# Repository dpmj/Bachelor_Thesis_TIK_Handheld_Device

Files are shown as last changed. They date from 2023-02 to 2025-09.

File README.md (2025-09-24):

# Tree Inspection Kit (TIK) hardware

This repository contains the hardware source from my bachelor's thesis in telecommunications engineering at the University of Granada, Spain, 2022. For the firmware, see this other repo: [Tree Inspection Kit (TIK) firmware](https://github.com/dpmj/bachelors-thesis-tree-inspection-kit-firmware).

This project marks the beginning of the development of a handheld device that can measure the modulus of elasticity of wood, a figure of great value for structural purposes, in a non-destructive way by analyzing acoustic signals. Developed with the help of the GranaSAT Electronics Aerospace Group and the IDIE-ADIME Institute, this project is part of the European LIFE Wood for Future initiative. The project encompasses every step in developing an electronic product, including conception, requirements specification, architecture and components selection, topology selection, circuit and PCB design, mechanical design, manufacturing, assembly, firmware, and prototype fabrication. 

Third-party desing elements included in this repository are subject to the copyright of their respective owners.

```bibtex
@phdthesis{dpmj-tfg-2022,
    title = {Development of an acoustic measurement system of the Modulus of Elasticity in trees, logs and boards},
    author = {{Del Pino Mena}, Juan},
    type = {Bachelor's thesis},
    school = {Universidad de Granada},
    year = {2022},
    month = {9},
    url = {https://hdl.handle.net/10481/80476},
    doi = {https://doi.org/10.5281/zenodo.13935041}
}
```

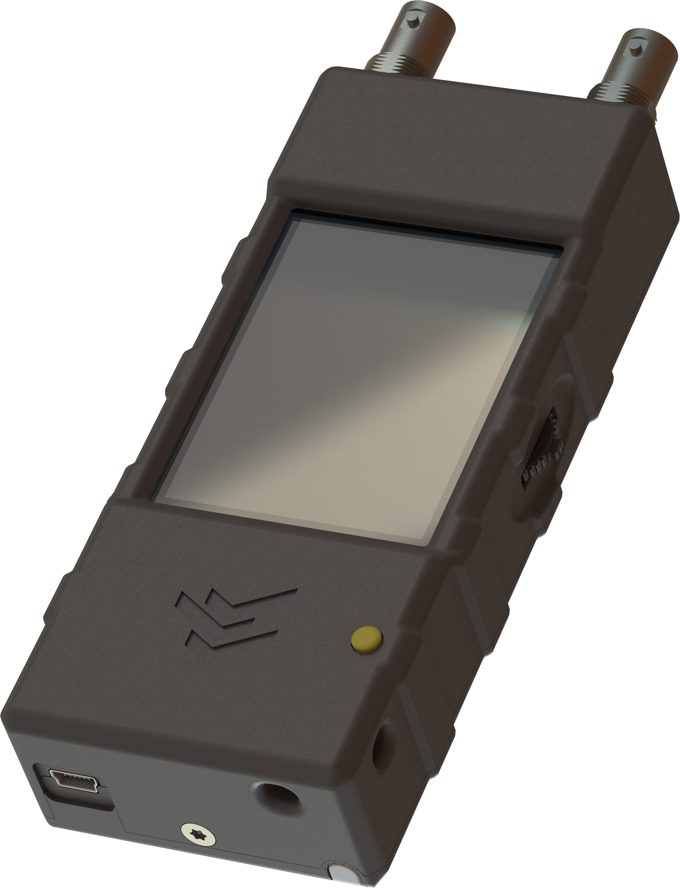
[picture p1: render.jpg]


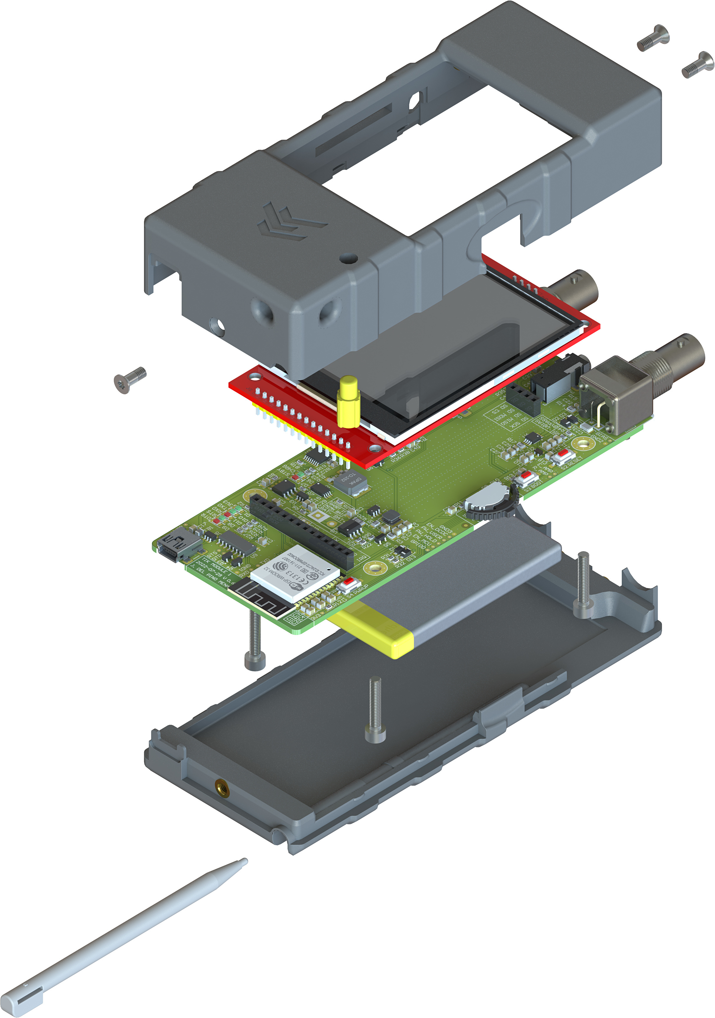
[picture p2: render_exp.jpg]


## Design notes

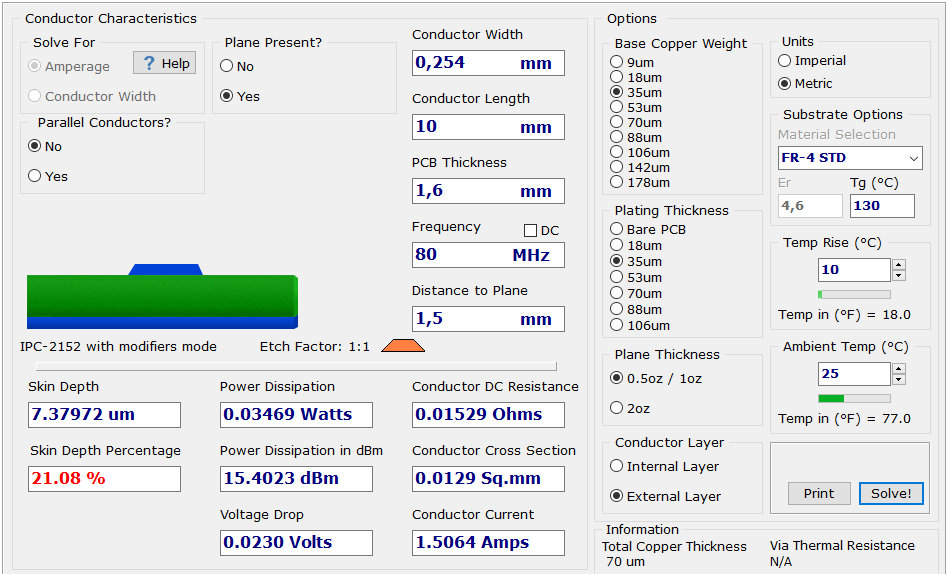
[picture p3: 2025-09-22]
ASSETS/IMAGES/SATURN PCB DESIGN/TRACE_0254mm_2.png

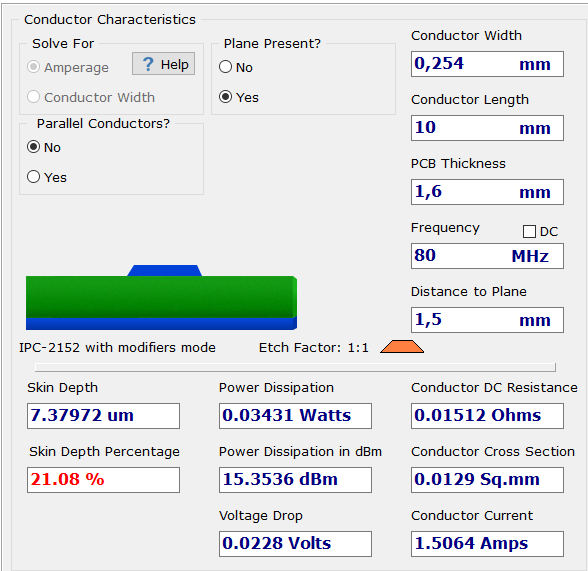
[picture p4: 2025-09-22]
ASSETS/IMAGES/SATURN PCB DESIGN/TRACE_0254mm.png

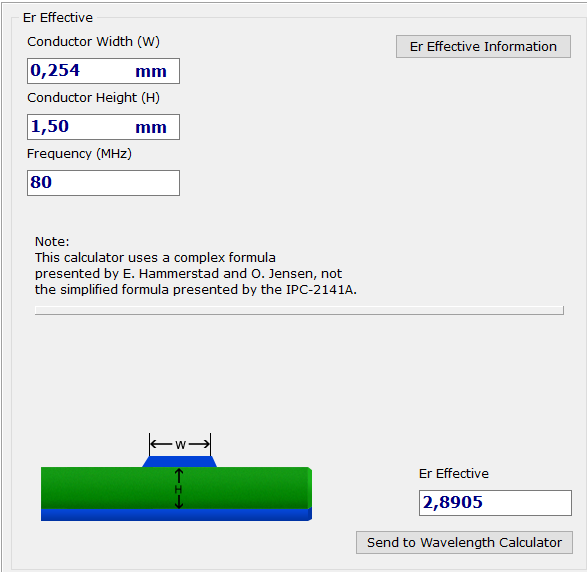
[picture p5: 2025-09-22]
ASSETS/IMAGES/SATURN PCB DESIGN/Er_Eff.png

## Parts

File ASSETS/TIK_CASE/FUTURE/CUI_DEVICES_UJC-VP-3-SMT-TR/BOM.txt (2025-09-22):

3DX_CUI_DEVICES_Supplier: CUI Devices
3DX_CUI_DEVICES_Description: Type C, 20 Vac, 3 A, Vertical, Surface Mount, Power-Only USB Receptacle
3DX_CUI_DEVICES_Model Number: UJC-VP-3-SMT-TR

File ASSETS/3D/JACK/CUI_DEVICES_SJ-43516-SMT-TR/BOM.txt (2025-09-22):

3DX_CUI_DEVICES_Supplier: CUI Devices
3DX_CUI_DEVICES_Description: 4 conductor 3.5 mm Surface Mount Audio Jack w/ Two Switch
3DX_CUI_DEVICES_Model Number: SJ-43516-SMT-TR

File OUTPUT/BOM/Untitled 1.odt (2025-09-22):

Designator | Value | Description | Quantity
C22 | 100pF | Ceramic cap size 0805 | 1
C23, C24 | 100nF | Ceramic cap size 1206 C1206C104K1RACTU | 2
C25 | 22pF | Ceramic cap size 0805 | 1
FB1, FB2 | 40mR, 3A 25% | 0805, 60O, 3A, 25% SMT | 2
J5 | | 3.5mm Jack 4-pole with normally closed switches | 1
J6 | | 3.5mm Jack 4-pole with normally closed switches | 1
L1 | 2.2uH | Shielded Power Inductor 2.2 uH 20% 2.2 A 50.4 mohms 3.11 A (sat) 60MHz 4018: 4x4x1.8mm | 1
Q1 | | Dual N-channel Enhancement mode power MOSFET | 1
Q2 | | MJD210 PNP BJT transistor DPAK (decawatt) 5A dc | 1
Q6 | | 65 V, 100 mA PNP general-purpose transistor | 1
R1 | 150K | Res size 0805 SMD mounting, low power Yageo-RC0805FR-07150KL | 1
R8 | 1.2K | Res size 0603 SMD mounting, low power | 1
R14, R17 | 1M | Res size 0805 SMD mounting, low power. Yageo-RC0805FR-071ML | 2
R23, R24 | 220 | Res size 0603 SMD mounting, low power | 2
R26, R27, R28, R29 | 150 | Res size 0603 SMD mounting, low power | 4
R36 | 22K | Res size 0603 SMD mounting, low power | 1
RT1 | 10K | NTC THERMISTOR 10K for solding a cable from the battery NTC | 1
U1 | | 1.0MHZ, 2A STEP-DOWN DC-DC BUCK CONVERTER, with latch-off protection | 1
U2 | LDO 1.8V, 80mA | Fixed output lowdropout linear regulator. 1.8 V 80 mA | 1
U6 | | LMV358IDGKR Dual OpAmp; low voltage rail to rail opamp; 2.7V to 5V Vss; ESD protection; MSOP-8 Package. | 1
U10 | | HX711 load cell amplifier | 1
U11 | | TPD3S014TDBVRQ1 ESD prot. & current limit | 1
C1, C14, C34 | 47pF | Ceramic cap size 0805 | 3
C2, C8, C13, C15, C17, C18, C20, C21, C27, C30, C31, C32, C33, C35, C37, C39, C40, C41, C42 | 100nF | Ceramic cap size 0805 | 19
C3, C16, C26, C29, C36, C38 | 10uF | Ceramic cap size 0805 | 6
C5 | 27pF | Ceramic cap size 0805 | 1
C4, C6, C7, C9, C12, C43 | 22uF | Ceramic cap size 0805 CC0805MKX5R6BB226 Yageo MLCC 22uF 10V 20% X5R | 6
C10, C11, C19 | 1uF | Ceramic cap size 0805 | 3
C28 | 470pF | Ceramic cap size 0805 | 1
D2, D3, D4, D5, D12, D13 | | SURFACE MOUNT FAST SWITCHING DIODE | 6
D1, D6, D8, D10 | | Low power LED color Green | 4
D7, D9, D11 | | Low power LED color Red | 3
J1 | | USB-MINI-B Female, Manufacturer PN/ID: 10033526-N3212LF | 1
J2, J3 | | BNC coaxial female connector | 2
J4 | | ILI9341 TFT LCD Jumper pin headers., plus SD card reader pins | 1
MCU1 | | - Transceiver; 802.11 b/g/n _Wi-Fi, WiFi, WLAN_, Bluetooth Smart Ready 4.x Dual Mode For Use With ESP-WROOM-32 | 1
Q3, Q4 | | | 2
Q5 | | PMOS BSS84AK | 1
R18, R21, R22 | 4.7K | Res size 0603 SMD mounting, low power | 3
R3 | 33K | Res size 0805 SMD mounting, low power | 1
R4, R5, R25 | 0R | Res size 0603 SMD mounting, zero-ohm 0R Yageo RC0603JR-070RL | 3
R9, R10, R11, R12, R13, R35, R37, R38, R39, R40 | 10K | Res size 0603 SMD mounting, low power | 10
R2, R6, R33, R34 | 100R | Res size 0603 SMD mounting, low power | 4
R7, R15, R16 | 1K | Res size 0603 SMD mounting, low power | 3
R19 | 1.5K | Res size 0603 SMD mounting, low power | 1
R20 | 0.2R | Res size 1206 SMD mounting, high power, shunt, current sense. | 1
R30, R31, R32 | 100K | Res size 0603 SMD mounting, low power | 3
S1 | | SWITCH Multidirection Slide Push Button SMD TS-003 | 1
S2, S3, S4 | | Generic 2 pin button | 3
U3 | | DW01A One cell Li-Po/Li-ion Battery protection IC | 1
U4 | | 1A Standalone Linear Li-lon Battery Charger with Thermal Regulation in SOP-8 | 1
U5 | | Very low capacitance ESD protection | 1
U7 | | LTC4060EFE | 1
U8 | | Zero-Drift, Bi-Directional CURRENT/POWER MONITOR with I2C. SOIC-8 (D) Package | 1
U9 | | USB to serial chip CH340C, integrated oscillator. | 1

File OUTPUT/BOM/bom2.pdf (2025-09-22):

# Bill of Materials

2175 Salk Avenue
Project Title: Bill of Materials for BOM Document [bill_of_materials.BomDoc] | Suite 200
Project File Name: TIK_HandheldDevice.PrjPcb | Carlsbad, CA 92008
Assembly Variant: None | USA
Part Number | Description | Designator | Manufacture | Manufacture Part Number | Supplier | Supplier Part Number | Supplier Unit Price | Quantity
Cap_cer_0603_100pF_5% Ceramic cap size 0805 | | C22 | | | | | | | 1
Cap_cer_1206_100nF_100V_10% | Ceramic cap size 1206 C1206C104K1RACTU | C23, C24 | | | | | | | 2
Cap_cer_0603_22pF_5% Ceramic cap size 0805 | | C25 | | | | | | | 1
Ferrite Bead Chip Fair-Rite 2508056007Y3 0805, 60Ω, 3A, 25% SMT | | FB1, FB2 | | | | | | | 2
CON EXPANSION_PORT | 3.5mm Jack 4-pole with normally closed switches | J5 | | | | | | | 1
CON LOAD CELL PORT JACK | 3.5mm Jack 4-pole with normally closed switches | J6 | | | | | | | 1
Ind 2uH_Wire_Shield_2A_4x4 | Shielded Power Inductor 2.2 uH 20% 2.2 A 50.4 mohms 3.11 A (sat) 60MHz 4018: 4x4x1.8mm | L1 | | | | | | | 1
IC FS8205A Dual NMOS | Dual N-channel Enhancement mode power MOSFET | Q1 | | | | | | | 1
PNP BJT MJD210 transistor | MJD210 PNP BJT transistor DPAK (decawatt) 5A dc | Q2 | | | | | | | 1
PNP BJT BC858 transistor | 65 V, 100 mA PNP general-purpose transistor | Q6 | | | | | | | 1
Res_0805_150K_1%_1/8W | Res size 0805 SMD mounting, low power Yageo-RC0805FR-07150KL | R1 | | | | | | | 1
Res_0603_1.2K_1%_100mW | Res size 0603 SMD mounting, low power | R8 | | | | | | | 1
Res_0805_1M_1% | Res size 0805 SMD mounting, low power. Yageo-RC0805FR-071ML | R14, R17 | | | | | | | 2
Res_0603_220_5%_100mW | Res size 0603 SMD mounting, low power | R23, R24 | | | | | | | 2
Res_0603_150_5%_100mW | Res size 0603 SMD mounting, low power | R26, R27, R28, R29 | | | | | | | 4
Res_0603_22K_5%_100mW | Res size 0603 SMD mounting, low power | R36 | | | | | | | 1
NTC 10K tht | NTC THERMISTOR 10K for solding a cable from the battery NTC | RT1 | | | | | | | 1
IC AP3429_A dcdc buck | 1.0MHZ, 2A STEP-DOWN DC-DC BUCK CONVERTER, with latch-off protection | U1 | | | | | | | 1
IC NCP562SQ18T1G LDO | Fixed output lowdropout linear regulator. 1.8 V 80 mA | U2 | | | | | | | 1
IC LMV358DGKR OpAmp | LMV358IDGKR Dual OpAmp; low voltage rail to rail opamp; 2.7V to 5V Vss; ESD protection; MSOP-8 Package. | U6 | | | | | | | 1
IC HX711 load cell amp HX711 load cell amplifier | | U10 | | | | | | | 1
IC TPD3S014 Current switch | TPD3S014TDBVRQ1 ESD prot. & current limit | U11 | | | | | | | 1
Cap_cer_0805_47pF_5% Ceramic cap size 0805 | | C1, C14, C34 | | | | | | | 3
Cap_cer_0805_100nF_10% Ceramic cap size 0805 | | C2, C8, C13, C15, C17, C18, C20, C21, C27, C30, C31, C32, C33, C35, C37, C39, C40, | | | | | | 19
Cap_cer_0805_10uF_10% Ceramic cap size 0805 | | C41, C42 C3, C16, C26, C29, C36, C38 | | | | | | | 6
Cap_cer_0805_27pF_5% Ceramic cap size 0805 | | C5 | | | | | | | 1
Cap_cer_0805_22uF_20% | Ceramic cap size 0805 CC0805MKX5R6BB226 Yageo MLCC 22uF 10V 20% X5R | C4, C6, C7, C9, C12, C43 | | | | | | | 6
Cap_cer_0805_1uF_10% Ceramic cap size 0805 | | C10, C11, C19 | | | | | | | 3
Cap_cer_0603_470pF_5% Ceramic cap size 0805 | | C28 | | | | | | | 1
Diode 1N4148W | SURFACE MOUNT FAST SWITCHING DIODE | D2, D3, D4, D5, D12, D13 | | | | | | | 6
Diode LED_G_0805Low power LED color Green | | D1, D6, D8, D10 | | | | | | | 4
Diode LED_R_0805Low power LED color Red | | D7, D9, D11 | | | | | | | 3
CON USB-MINI-B Female | USB-MINI-B Female, Manufacturer PN/ID: 10033526-N3212LF | J1 | | | | | | | 1
CON BNC Female Socket | BNC coaxial female connector | J2, J3 | | | | | | | 2
MOD ILI9341 TFT LCD + SD CARD READER | ILI9341 TFT LCD Jumper pin headers., plus SD card reader pins | J4 | | | | | | | 1
MCU ESP32-WROOM-32D | - Transceiver; 802.11 b/g/n _Wi-Fi, WiFi, WLAN_, Bluetooth Smart Ready 4.x Dual Mode For Use With ESP-WROOM-32 | MCU1 | | | | | | | 1
NMOS 2N7002 | | Q3, Q4 | | | | | | | 2
PMOS BSS84AK | PMOS BSS84AK | Q5 | | | | | | | 1
Res_0603_4.7K_1%_100mW | Res size 0603 SMD mounting, low power | R18, R21, R22 | | | | | | | 3
Res_0805_33K_1%_1/8W | Res size 0805 SMD mounting, low power | R3 | | | | | | | 1
Res_0603_0ohm | Res size 0603 SMD mounting, zero-ohm 0R Yageo RC0603JR-070RL | R4, R5, R25 | | | | | | | 3
Res_0603_10K_5%_100mW_1 | Res size 0603 SMD mounting, low power | R9, R10, R11, R12, R13, R35, R37, R38, R39, R40 | | | | | | 10
Res_0603_100R_5%_100mW | Res size 0603 SMD mounting, low power | R2, R6, R33, R34 | | | | | | | 4
Res_0603_1K_5%_100mW | Res size 0603 SMD mounting, low power | R7, R15, R16 | | | | | | | 3
Res_0603_1.5K_1%_100mW | Res size 0603 SMD mounting, low power | R19 | | | | | | | 1
Res_1206_0R2_1%_500mW | Res size 1206 SMD mounting, high power, shunt, current sense. | R20 | | | | | | | 1
Res_0603_100K_5%_100mW | Res size 0603 SMD mounting, low power | R30, R31, R32 | | | | | | | 3
SWITCH Multidirection Slide Push Button SMD TS-003 | SWITCH Multidirection Slide Push Button SMD TS-003 | S1 | | | | | | | 1
Button | Generic 2 pin button | S2, S3, S4 | | | | | | | 3
IC DW01A bat protection | DW01A One cell Li-Po/Li-ion Battery protection IC | U3 | | | | | | | 1
IC TP4056 BAT Charger | 1A Standalone Linear Li-lon Battery Charger with Thermal Regulation in SOP- | U4 | | | | | | | 1
IC USBLC6-2SC6 ESD Prot | 8 Very low capacitance ESD protection | U5 | | | | | | | 1
IC LTC4060EFE Bat NiMH charger LTC4060EFE | | U7 | | | | | | | 1
IC INA219 current sense | Zero-Drift, Bi-Directional CURRENT/POWER MONITOR with I2C. SOIC-8 | U8 | | | | | | | 1
IC CH340C usb to ttl | (D) Package USB to serial chip CH340C, integrated oscillator. | U9 | | | | | | | 1
| $0,00 128
Approved | Notes

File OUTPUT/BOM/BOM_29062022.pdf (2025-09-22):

BOM_29062022

Line #

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
Designator

C22
C23, C24
C25
FB1, FB2
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
R14, R17
R23, R24
R26, R27, R28, R29
R36
RT1
U1

U2
U6
U10
U11
C1, C14, C34
C2, C8, C13, C15, C17, C18, C20, C21, C27, C30, C31, C32, C33, C35, C37, C39, C40, C41, C42 C3, C16, C26, C29, C36, C38
C5
C4, C6, C7, C9, C12, C43
C10, C11, C19
C28
D2, D3, D4, D5, D12, D13
D1, D6, D8, D10
D7, D9, D11
J1
J2, J3
J4
MCU1
Q3, Q4
Q5
R18, R21, R22
R3
R4, R5, R25
R9, R10, R11, R12, R13, R35, R37, R38, R39, R40 R2, R6, R33, R34
R7, R15, R16
R19
R20
R30, R31, R32
S1

S2, S3, S4
U3
U4
U5
U7
U8
U9

Value | Description | Quantity
100pF | Ceramic cap size 0805 | 1
100nF | Ceramic cap size 1206 C1206C104K1RACTU | 2
22pF | Ceramic cap size 0805 | 1
40mR, 3A 25% | 0805, 60O, 3A, 25% SMT | 2
| 3.5mm Jack 4-pole with normally closed switches | 1
| 3.5mm Jack 4-pole with normally closed switches | 1
2.2uH | Shielded Power Inductor 2.2 uH 20% 2.2 A 50.4 mohms 3.11 A (sat) 60MHz 4018: 4x4x1.8mm | 1
| Dual N-channel Enhancement mode power MOSFET | 1
| MJD210 PNP BJT transistor DPAK (decawatt) 5A dc | 1
| 65 V, 100 mA PNP general-purpose transistor | 1
150K | Res size 0805 SMD mounting, low power Yageo-RC0805FR-07150KL | 1
1.2K | Res size 0603 SMD mounting, low power | 1
1M | Res size 0805 SMD mounting, low power. Yageo-RC0805FR-071ML | 2
220 Res size 0603 SMD mounting, low power | | 2
150 Res size 0603 SMD mounting, low power | | 4
22K | Res size 0603 SMD mounting, low power | 1
10K | NTC THERMISTOR 10K for solding a cable from the battery NTC | 1
| 1.0MHZ, 2A STEP-DOWN DC-DC BUCK CONVERTER, with latch-off prote | 1
LDO 1.8V, 80mA | Fixed output lowdropout linear regulator. 1.8 V 80 mA | 1
| LMV358IDGKR Dual OpAmp; low voltage rail to rail opamp; 2.7V to 5V Vs | 1
| HX711 load cell amplifier | 1
| TPD3S014TDBVRQ1 ESD prot. & current limit | 1
47pF | Ceramic cap size 0805 | 3
100nF | Ceramic cap size 0805 | 19
10uF | Ceramic cap size 0805 | 6
27pF | Ceramic cap size 0805 | 1
22uF | Ceramic cap size 0805 CC0805MKX5R6BB226 Yageo MLCC 22uF 10V 2 | 6
1uF | Ceramic cap size 0805 | 3
470pF | Ceramic cap size 0805 | 1
| SURFACE MOUNT FAST SWITCHING DIODE | 6
| Low power LED color Green | 4
| Low power LED color Red | 3
| USB-MINI-B Female, Manufacturer PN/ID: 10033526-N3212LF | 1
| BNC coaxial female connector | 2
| ILI9341 TFT LCD Jumper pin headers., plus SD card reader pins | 1
| - Transceiver; 802.11 b/g/n _Wi-Fi, WiFi, WLAN_, Bluetooth Smart Rea | 1
| | 2
| PMOS BSS84AK | 1
4.7K | Res size 0603 SMD mounting, low power | 3
33K | Res size 0805 SMD mounting, low power | 1
0R | Res size 0603 SMD mounting, zero-ohm 0R Yageo RC0603JR-070RL | 3
10K | Res size 0603 SMD mounting, low power | 10
100R | Res size 0603 SMD mounting, low power | 4
1K | Res size 0603 SMD mounting, low power | 3
1.5K | Res size 0603 SMD mounting, low power | 1
0.2R | Res size 1206 SMD mounting, high power, shunt, current sense. | 1
100K | Res size 0603 SMD mounting, low power | 3
| SWITCH Multidirection Slide Push Button SMD TS-003 | 1

Generic 2 pin button | 3
DW01A One cell Li-Po/Li-ion Battery protection IC | 1
1A Standalone Linear Li-lon Battery Charger with Thermal Regulation in | 1
Very low capacitance ESD protection | 1
LTC4060EFE | 1
Zero-Drift, Bi-Directional CURRENT/POWER MONITOR with I2C. SOIC-8 | 1
USB to serial chip CH340C, integrated oscillator. | 1

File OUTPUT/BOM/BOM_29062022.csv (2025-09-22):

Line # | Designator | Value | Description | Quantity | FabGroup | FabOrder
 | C22 | 100pF | Ceramic cap size 0805 | 1
 | C23, C24 | 100nF | Ceramic cap size 1206 C1206C104K1RACTU | 2
 | C25 | 22pF | Ceramic cap size 0805 | 1
 | FB1, FB2 | 40mR, 3A 25% | 0805, 60O, 3A, 25% SMT | 2
 | J5 |  | 3.5mm Jack 4-pole with normally closed switches | 1
 | J6 |  | 3.5mm Jack 4-pole with normally closed switches | 1
 | L1 | 2.2uH | Shielded Power Inductor 2.2 uH 20% 2.2 A 50.4 mohms 3.11 A (sat) 60MHz 4018: 4x4x1.8mm | 1 | DCDC converter | 2
 | Q1 |  | Dual N-channel Enhancement mode power MOSFET | 1
 | Q2 |  | MJD210 PNP BJT transistor DPAK (decawatt) 5A dc | 1
 | Q6 |  | 65 V, 100 mA PNP general-purpose transistor | 1
 | R1 | 150K | Res size 0805 SMD mounting, low power Yageo-RC0805FR-07150KL | 1
 | R8 | 1.2K | Res size 0603 SMD mounting, low power | 1
 | R14, R17 | 1M | Res size 0805 SMD mounting, low power. Yageo-RC0805FR-071ML | 2
 | R23, R24 | 220 | Res size 0603 SMD mounting, low power | 2
 | R26, R27, R28, R29 | 150 | Res size 0603 SMD mounting, low power | 4
 | R36 | 22K | Res size 0603 SMD mounting, low power | 1
 | RT1 | 10K | NTC THERMISTOR 10K for solding a cable from the battery NTC | 1
 | U1 |  | 1.0MHZ, 2A STEP-DOWN DC-DC BUCK CONVERTER, with latch-off protection | 1
 | U2 | LDO 1.8V, 80mA | Fixed output lowdropout linear regulator. 1.8 V 80 mA | 1
 | U6 |  | LMV358IDGKR Dual OpAmp; low voltage rail to rail opamp; 2.7V to 5V Vss; ESD protection; MSOP-8 Package. | 1
 | U10 |  | HX711 load cell amplifier | 1
 | U11 |  | TPD3S014TDBVRQ1 ESD prot. & current limit | 1
4 | C1, C14, C34 | 47pF | Ceramic cap size 0805 | 3 | Microcontroller, LDO Regulator & LDO bypass, [NoParam] | 1, 12, [NoParam]
5 | C2, C8, C13, C15, C17, C18, C20, C21, C27, C30, C31, C32, C33, C35, C37, C39, C40, C41, C42 | 100nF | Ceramic cap size 0805 | 19 | Microcontroller, DCDC converter, LDO Regulator & LDO bypass, Charger for Li-Ion, USB Port, Buttons - Reset, Buttons - Boot, Buttons - Multipurpose, Signal conditioning, USB to UART & Programming, LCD TFT Display, Buttons - Powerup button, [NoParam] | 1, 2, 12, 4, 11, 10, 9, 13, 3, 15, [NoParam]
6 | C3, C16, C26, C29, C36, C38 | 10uF | Ceramic cap size 0805 | 6 | Microcontroller, Charger for Li-Ion, Signal conditioning, Battery, [NoParam] | 1, 4, 13, 7, [NoParam]
7 | C5 | 27pF | Ceramic cap size 0805 | 1 | DCDC converter | 2
8 | C4, C6, C7, C9, C12, C43 | 22uF | Ceramic cap size 0805 CC0805MKX5R6BB226 Yageo MLCC 22uF 10V 20% X5R | 6 | [NoParam], DCDC converter, LDO Regulator & LDO bypass | [NoParam], 2, 12
9 | C10, C11, C19 | 1uF | Ceramic cap size 0805 | 3 | LDO Regulator & LDO bypass, Buttons - Reset | 12, 11
12 | C28 | 470pF | Ceramic cap size 0805 | 1 | Charger for Ni-MH | 6
13 | D2, D3, D4, D5, D12, D13 |  | SURFACE MOUNT FAST SWITCHING DIODE | 6 | Signal conditioning, Buttons - Powerup button | 13, 3
14 | D1, D6, D8, D10 |  | Low power LED color Green | 4 | DCDC converter, Charging status, USB to UART & Programming | 2, 5, 3
15 | D7, D9, D11 |  | Low power LED color Red | 3 | Charging status, USB to UART & Programming | 5, 3
18 | J1 |  | USB-MINI-B Female, Manufacturer PN/ID: 10033526-N3212LF | 1 | USB Port | 2
19 | J2, J3 |  | BNC coaxial female connector | 2
20 | J4 |  | ILI9341 TFT LCD Jumper pin headers., plus SD card reader pins | 1 | LCD TFT Display | 15
22 | MCU1 |  | - Transceiver; 802.11 b/g/n _Wi-Fi, WiFi, WLAN_, Bluetooth Smart Ready 4.x Dual Mode For Use With ESP-WROOM-32 | 1 | Microcontroller | 1
25 | Q3, Q4 |  |  | 2 | USB to UART & Programming | 3
26 | Q5 |  | PMOS BSS84AK | 1 | Buttons - Powerup button | 3
27 | R18, R21, R22 | 4.7K | Res size 0603 SMD mounting, low power | 3
29 | R3 | 33K | Res size 0805 SMD mounting, low power | 1
30 | R4, R5, R25 | 0R | Res size 0603 SMD mounting, zero-ohm 0R Yageo RC0603JR-070RL | 3 | LDO Regulator & LDO bypass, Battery | 12, 7
31 | R9, R10, R11, R12, R13, R35, R37, R38, R39, R40 | 10K | Res size 0603 SMD mounting, low power | 10
32 | R2, R6, R33, R34 | 100R | Res size 0603 SMD mounting, low power | 4
33 | R7, R15, R16 | 1K | Res size 0603 SMD mounting, low power | 3
38 | R19 | 1.5K | Res size 0603 SMD mounting, low power | 1
39 | R20 | 0.2R | Res size 1206 SMD mounting, high power, shunt, current sense. | 1
40 | R30, R31, R32 | 100K | Res size 0603 SMD mounting, low power | 3
42 | S1 |  | SWITCH Multidirection Slide Push Button SMD TS-003 | 1 | Buttons - Multipurpose | 9
43 | S2, S3, S4 |  | Generic 2 pin button | 3 | Buttons - Reset, Buttons - Boot, Buttons - Powerup button | 11, 10, 3
46 | U3 |  | DW01A One cell Li-Po/Li-ion Battery protection IC | 1 | Charger for Li-Ion | 4
47 | U4 |  | 1A Standalone Linear Li-lon Battery Charger with Thermal Regulation in SOP-8 | 1
48 | U5 |  | Very low capacitance ESD protection | 1 | USB Port | 2
50 | U7 |  | LTC4060EFE | 1
51 | U8 |  | Zero-Drift, Bi-Directional CURRENT/POWER MONITOR with I2C. SOIC-8 (D) Package | 1
52 | U9 |  | USB to serial chip CH340C, integrated oscillator. | 1 | USB to UART & Programming | 3

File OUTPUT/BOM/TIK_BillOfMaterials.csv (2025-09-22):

Line # | Designator | Name | Description | Value | PackageDescription | FabGroup | FabOrder | Manufacturer 1 | Manufacturer Part Number 1 | Manufacturer Lifecycle 1 | Supplier 1 | Supplier Part Number 1 | Supplier Unit Price 1 | Supplier Subtotal 1
1 | 3V3 | Test Point Pad dual sided | Test point - PCB Pad dual sided |  |  | DCDC converter | 2
1 | BAT_CHRG | Test Point Pad dual sided | Test point - PCB Pad dual sided |  |  | Charging status | 5
1 | BAT_STBY | Test Point Pad dual sided | Test point - PCB Pad dual sided |  |  | Charging status | 5
1 | DTR | Test Point Pad dual sided | Test point - PCB Pad dual sided |  |  | USB to UART & Programming | 3
1 | E_AMP | Test Point Pad dual sided | Test point - PCB Pad dual sided |  |  | Signal conditioning | 13
1 | E_IN | Test Point Pad dual sided | Test point - PCB Pad dual sided |  |  | Signal conditioning | 13
1 | EN_DCDC | Test Point Pad dual sided | Test point - PCB Pad dual sided |  |  | DCDC converter | 2
1 | EN_LDO | Test Point Pad dual sided | Test point - PCB Pad dual sided |  |  | LDO Regulator & LDO bypass | 12
1 | EN_MCU | Test Point Pad dual sided | Test point - PCB Pad dual sided |  |  | Buttons - Reset | 11
1 | GND1 | Test Point Pad dual sided | Test point - PCB Pad dual sided
1 | GND2 | Test Point Pad dual sided | Test point - PCB Pad dual sided
1 | GND3 | Test Point Pad dual sided | Test point - PCB Pad dual sided
1 | GND4 | Test Point Pad dual sided | Test point - PCB Pad dual sided
1 | GPIO0 | Test Point Pad dual sided | Test point - PCB Pad dual sided |  |  | Buttons - Boot | 10
1 | PWUP_HOLD | Test Point Pad dual sided | Test point - PCB Pad dual sided |  |  | Buttons - Powerup button | 3
1 | PWUP_USER | Test Point Pad dual sided | Test point - PCB Pad dual sided |  |  | Buttons - Powerup button | 3
1 | R_AMP | Test Point Pad dual sided | Test point - PCB Pad dual sided |  |  | Signal conditioning | 13
1 | R_IN | Test Point Pad dual sided | Test point - PCB Pad dual sided |  |  | Signal conditioning | 13
1 | RTS | Test Point Pad dual sided | Test point - PCB Pad dual sided |  |  | USB to UART & Programming | 3
1 | RXD | Test Point Pad dual sided | Test point - PCB Pad dual sided |  |  | USB to UART & Programming | 3
1 | TXD | Test Point Pad dual sided | Test point - PCB Pad dual sided |  |  | USB to UART & Programming | 3
1 | VBAT- | Test Point Pad dual sided | Test point - PCB Pad dual sided |  |  | Battery | 7
1 | VBAT+ | Test Point Pad dual sided | Test point - PCB Pad dual sided |  |  | Battery | 7
1 | VBIAS | Test Point Pad dual sided | Test point - PCB Pad dual sided |  |  | Signal conditioning | 13
1 | VMEAS | Test Point Pad dual sided | Test point - PCB Pad dual sided |  |  | Battery current sense | 8
1 | VUSB | Test Point Pad dual sided | Test point - PCB Pad dual sided |  |  | USB Port | 2
2 | BAT1 | Battery pads | Generic 2-Pad battery connector |  |  | Battery | 7
3 | C1 | Cap_pol_wcap | Electrolytic capacitor packaging WCAP-ASLL for SMD mounting | 100uF | WCAP-ASLL | Microcontroller | 1
4 | C2 | Cap_cer_0805 | Ceramic cap size 0805 | 47pF | 0805 | Microcontroller | 1
4 | C14 | Cap_cer_0805 | Ceramic cap size 0805 | 47pF | 0805 | LDO Regulator & LDO bypass | 12
5 | C3 | Cap_cer_0805 | Ceramic cap size 0805 | 100nF | 0805 | Microcontroller | 1
5 | C8 | Cap_cer_0805 | Ceramic cap size 0805 | 100nF | 0805 | DCDC converter | 2
5 | C13 | Cap_cer_0805 | Ceramic cap size 0805 | 100nF | 0805 | LDO Regulator & LDO bypass | 12
5 | C15 | Cap_cer_0805 | Ceramic cap size 0805 | 100nF | 0805 | Charger for Li-Ion | 4
5 | C17 | Cap_cer_0805 | Ceramic cap size 0805 | 100nF | 0805 | USB Port | 2
5 | C18 | Cap_cer_0805 | Ceramic cap size 0805 | 100nF | 0805 | Buttons - Multipurpose | 9
5 | C19 | Cap_cer_0805 | Ceramic cap size 0805 | 100nF | 0805 | Buttons - Reset | 11
5 | C21 | Cap_cer_0805 | Ceramic cap size 0805 | 100nF | 0805 | Buttons - Boot | 10
5 | C25 | Cap_cer_0805 | Ceramic cap size 0805 | 100nF | 0805 | Signal conditioning | 13
5 | C28 | Cap_cer_0805 | Ceramic cap size 0805 | 100nF | 0805 | USB to UART & Programming | 3
5 | C29 | Cap_cer_0805 | Ceramic cap size 0805 | 100nF | 0805 | LCD TFT Display | 15
5 | C30 | Cap_cer_0805 | Ceramic cap size 0805 | 100nF | 0805 | Buttons - Powerup button | 3
6 | C4 | Cap_cer_0805 | Ceramic cap size 0805 | 10uF | 0805 | Microcontroller | 1
6 | C16 | Cap_cer_0805 | Ceramic cap size 0805 | 10uF | 0805 | Charger for Li-Ion | 4
6 | C24 | Cap_cer_0805 | Ceramic cap size 0805 | 10uF | 0805 | Signal conditioning | 13
6 | C27 | Cap_cer_0805 | Ceramic cap size 0805 | 10uF | 0805 | Battery | 7
7 | C5 | Cap_cer_0805 | Ceramic cap size 0805 | 27pF | 0805 | DCDC converter | 2
8 | C6 | Cap_cer_0805 | Ceramic cap size 0805 CC0805MKX5R6BB226 Yageo MLCC 22uF 10V 20% X5R | 22uF | 0805 | DCDC converter | 2
8 | C7 | Cap_cer_0805 | Ceramic cap size 0805 CC0805MKX5R6BB226 Yageo MLCC 22uF 10V 20% X5R | 22uF | 0805 | DCDC converter | 2
8 | C9 | Cap_cer_0805 | Ceramic cap size 0805 CC0805MKX5R6BB226 Yageo MLCC 22uF 10V 20% X5R | 22uF | 0805 | DCDC converter | 2
8 | C12 | Cap_cer_0805 | Ceramic cap size 0805 CC0805MKX5R6BB226 Yageo MLCC 22uF 10V 20% X5R | 22uF | 0805 | LDO Regulator & LDO bypass | 12
9 | C10 | Cap_cer_0805 | Ceramic cap size 0805 | 1uF | 0805 | LDO Regulator & LDO bypass | 12
9 | C11 | Cap_cer_0805 | Ceramic cap size 0805 | 1uF | 0805 | LDO Regulator & LDO bypass | 12
9 | C20 | Cap_cer_0805 | Ceramic cap size 0805 | 1uF | 0805 | Buttons - Reset | 11
10 | C22 | Cap_cer_0805_4.7pF_5% | Ceramic cap size 0805 GRM1555C1H4R7BA01D | 4.7pF | 0805 | Signal conditioning | 13
11 | C23 | Cap_cer_0603_47pF_5% | Ceramic cap size 0805 | 47pF | 0805 | Signal conditioning | 13
12 | C26 | Cap_cer_0603_470pF_5% | Ceramic cap size 0805 | 470pF | 0603 | Charger for Ni-MH | 6
13 | D1 | Diode 1N4148W | SURFACE MOUNT FAST SWITCHING DIODE |  | SOD123 | Signal conditioning | 13
13 | D2 | Diode 1N4148W | SURFACE MOUNT FAST SWITCHING DIODE |  | SOD123 | Signal conditioning | 13
13 | D3 | Diode 1N4148W | SURFACE MOUNT FAST SWITCHING DIODE |  | SOD123 | Signal conditioning | 13
13 | D4 | Diode 1N4148W | SURFACE MOUNT FAST SWITCHING DIODE |  | SOD123 | Signal conditioning | 13
13 | D9 | Diode 1N4148W | SURFACE MOUNT FAST SWITCHING DIODE |  | SOD123 | Buttons - Powerup button | 3
13 | D10 | Diode 1N4148W | SURFACE MOUNT FAST SWITCHING DIODE |  | SOD123 | Buttons - Powerup button | 3
14 | D5 | Diode LED_G_0805 | Low power LED color Green |  | 0805 | DCDC converter | 2
14 | D6 | Diode LED_G_0805 | Low power LED color Green |  | 0805 | Charging status | 5
14 | D8 | Diode LED_G_0805 | Low power LED color Green |  | 0805 | USB to UART & Programming | 3
14 | D12 | Diode LED_G_0805 | Low power LED color Green |  | 0805 | USB to UART & Programming | 3
15 | D7 | Diode LED_R_0805 | Low power LED color Red |  | 0805 | Charging status | 5
15 | D11 | Diode LED_R_0805 | Low power LED color Red |  | 0805 | USB to UART & Programming | 3
15 | D13 | Diode LED_R_0805 | Low power LED color Red |  | 0805 | USB to UART & Programming | 3
16 | F1 | Fiducial_1mm_2mm | Fiducial 1mm pad, 2mm solder resist
16 | F2 | Fiducial_1mm_2mm | Fiducial 1mm pad, 2mm solder resist
16 | F3 | Fiducial_1mm_2mm | Fiducial 1mm pad, 2mm solder resist
17 | FB1 | Ferrite Bead Chip Fair-Rite 2508056007Y3 | 0805, 60O, 3A, 25% SMT | 40mR, 3A |  | USB Port | 2
18 | J1 | USB-MINI-B Female | USB-MINI-B Female, Manufacturer PN/ID: 10033526-N3212LF |  | USB-Mini-B, F | USB Port | 2
19 | J2 | BNC-Female | BNC coaxial female connector |  |  | BNC connectors | 14
19 | J3 | BNC-Female | BNC coaxial female connector |  |  | BNC connectors | 14
20 | J4 | ILI9341 TFT LCD | ILI9341 TFT LCD Jumper pin headers., plus SD card reader pins |  | 100 mil pitch | LCD TFT Display | 15
21 | L1 | Ind 2uH_Wire_Shield_2A_4x4 | Shielded Power Inductor 2.2 uH 20% 2.2 A 50.4 mohms 3.11 A (sat) 60MHz 4018: 4x4x1.8mm | 2.2uH | 4x4x1.8mm | DCDC converter | 2
22 | MCU1 | MCU ESP32-WROOM-32D | - Transceiver; 802.11 b/g/n _Wi-Fi, WiFi, WLAN_, Bluetooth Smart Ready 4.x Dual Mode For Use With ESP-WROOM-32 |  |  | Microcontroller | 1
23 | Q1 | FS825A | Dual N-channel Enhancement mode power MOSFET |  | TSSOP-8 | Charger for Li-Ion | 4
24 | Q2 | MJD210 PNP BJT transistor | MJD210 PNP BJT transistor DPAK (decawatt) 5A dc |  | DPAK (TO-252) | Charger for Ni-MH | 6
25 | Q3 | NMOS 2N7002 |  |  | SOT23 | USB to UART & Programming | 3
25 | Q4 | NMOS 2N7002 |  |  | SOT23 | USB to UART & Programming | 3
26 | Q5 | PMOS BSS84AK | PMOS BSS84AK |  | SOT23 | Buttons - Powerup button | 3
27 | R1 | Res_0603_4.7K_1%_100mW | Res size 0603 SMD mounting, low power | 4.7K | 0603 | Battery current sense | 8
27 | R2 | Res_0603_4.7K_1%_100mW | Res size 0603 SMD mounting, low power | 4.7K | 0603 | Battery current sense | 8
27 | R22 | Res_0603_4.7K_1%_100mW | Res size 0603 SMD mounting, low power | 4.7K | 0603 | Charger for Ni-MH | 6
28 | R3 | Res_0805_150K_1%_1/8W | Res size 0805 SMD mounting, low power Yageo-RC0805FR-07150KL | 150K | 0805 | DCDC converter | 2
29 | R4 | Res_0805_33K_1%_1/8W | Res size 0805 SMD mounting, low power | 33K | 0805 | DCDC converter | 2
30 | R5 | Res_0603_0ohm | Res size 0603 SMD mounting, zero-ohm 0R Yageo RC0603JR-070RL | 0R | 0603 | LDO Regulator & LDO bypass | 12
30 | R7 | Res_0603_0ohm | Res size 0603 SMD mounting, zero-ohm 0R Yageo RC0603JR-070RL | 0R | 0603 | LDO Regulator & LDO bypass | 12
30 | R28 | Res_0603_0ohm | Res size 0603 SMD mounting, zero-ohm 0R Yageo RC0603JR-070RL | 0R | 0603 | Battery | 7
31 | R6 | Res_0603_10K_5%_100mW_1 | Res size 0603 SMD mounting, low power | 10K | 0603 | LDO Regulator & LDO bypass | 12
31 | R13 | Res_0603_10K_5%_100mW_1 | Res size 0603 SMD mounting, low power | 10K | 0603 | Buttons - Multipurpose | 9
31 | R14 | Res_0603_10K_5%_100mW_1 | Res size 0603 SMD mounting, low power | 10K | 0603 | Buttons - Multipurpose | 9
31 | R15 | Res_0603_10K_5%_100mW_1 | Res size 0603 SMD mounting, low power | 10K | 0603 | Buttons - Multipurpose | 9
31 | R16 | Res_0603_10K_5%_100mW_1 | Res size 0603 SMD mounting, low power | 10K | 0603 | Buttons - Reset | 11
31 | R17 | Res_0603_10K_5%_100mW_1 | Res size 0603 SMD mounting, low power | 10K | 0603 | Buttons - Boot | 10
32 | R8 | Res_0603_100R_5%_100mW | Res size 0603 SMD mounting, low power | 100R | 0603 | Charger for Li-Ion | 4
33 | R11 | Res_0603_1K_5%_100mW | Res size 0603 SMD mounting, low power | 1K | 0603 | Charger for Li-Ion | 4
33 | R26 | Res_0603_1K_5%_100mW | Res size 0603 SMD mounting, low power | 1K | 0603 | Charging status | 5
33 | R27 | Res_0603_1K_5%_100mW | Res size 0603 SMD mounting, low power | 1K | 0603 | Charging status | 5
33 | R29 | Res_0603_1K_5%_100mW | Res size 0603 SMD mounting, low power | 1K | 0603 | USB to UART & Programming | 3
33 | R30 | Res_0603_1K_5%_100mW | Res size 0603 SMD mounting, low power | 1K | 0603 | USB to UART & Programming | 3
33 | R34 | Res_0603_1K_5%_100mW | Res size 0603 SMD mounting, low power | 1K | 0603 | DCDC converter | 2
33 | R35 | Res_0603_1K_5%_100mW | Res size 0603 SMD mounting, low power | 1K | 0603 | USB to UART & Programming | 3
33 | R36 | Res_0603_1K_5%_100mW | Res size 0603 SMD mounting, low power | 1K | 0603 | USB to UART & Programming | 3
34 | R12 | Res_0603_2.7K_5%_100mW | Res size 0603 SMD mounting, low power | 2.7K | 0603 | Charger for Li-Ion | 4
35 | R18 | Yageo-RC0805FR-072ML | Res size 0805 SMD mounting, low power. Yageo-RC0805FR-072ML | 2M | 0805 | Signal conditioning | 13
35 | R21 | Yageo-RC0805FR-072ML | Res size 0805 SMD mounting, low power. Yageo-RC0805FR-072ML | 2M | 0805 | Signal conditioning | 13
36 | R19 | RS-05K101JT | Res size 0805 SMD mounting, low power. | 100 | 0805 | Signal conditioning | 13
37 | R20 | Yageo-RC0805FR-0739KL | Res size 0805 SMD mounting, low power. Yageo-RC0805FR-0739KL | 39K | 0805 | Signal conditioning | 13
38 | R24 | Res_0603_1.5K_1%_100mW | Res size 0603 SMD mounting, low power | 1.5K | 0603 | Charger for Ni-MH | 6
39 | R25 | sense | Res size 1206 SMD mounting, high power, shunt, current sense. | 0.2R | 1206 | Battery current sense | 8
40 | R31 | Res_0603_100K_5%_100mW | Res size 0603 SMD mounting, low power | 100K | 0603 | Buttons - Powerup button | 3
40 | R32 | Res_0603_100K_5%_100mW | Res size 0603 SMD mounting, low power | 100K | 0603 | Buttons - Powerup button | 3
40 | R33 | Res_0603_100K_5%_100mW | Res size 0603 SMD mounting, low power | 100K | 0603 | Buttons - Powerup button | 3
41 | RT1 | NTC 10K | NTC THERMISTOR 10K 0603 | 10K | 0603 | Battery | 7
42 | S1 | SWITCH Multidirection Slide Push Button SMD TS-003 | SWITCH Multidirection Slide Push Button SMD TS-003 |  |  | Buttons - Multipurpose | 9
43 | S2 | Button | Generic 2 pin button |  | SMD 2-pin | Buttons - Reset | 11
43 | S3 | Button | Generic 2 pin button |  | SMD 2-pin | Buttons - Boot | 10
43 | S4 | Button | Generic 2 pin button |  | SMD 2-pin | Buttons - Powerup button | 3
44 | U1 | AP3429_A | 1.0MHZ, 2A STEP-DOWN DC-DC BUCK CONVERTER |  | TSOT-25 | DCDC converter | 2
45 | U2 | IC NCP562SQ18T1G LDO | Fixed output lowdropout linear regulator. 1.8 V 80 mA | 1.8V 80mA | SC82-AB (SC70-4) | LDO Regulator & LDO bypass | 12
46 | U3 | DW01A | DW01A One cell Li-Po/Li-ion Battery protection IC |  | SOT-23-6 | Charger for Li-Ion | 4
47 | U4 | TP4056 | 1A Standalone Linear Li-lon Battery Charger with Thermal Regulation in SOP-8 |  | SOP-8 | Charger for Li-Ion | 4
48 | U5 | IC USBLC6-2SC6 ESD Prot | Very low capacitance ESD protection |  | SOT23-6L | USB Port | 2
49 | U6 | IC LMV358DGKR OpAmp | LMV358-DGK-R Dual OpAmp; low voltage rail to rail opamp; 2.7V to 5V Vss; ESD protection; MSOP-8 Package. |  | MSOP-8 | Signal conditioning | 13
50 | U7 | IC LTC4060EFE Bat NiMH charger | LTC4060EFE |  | TSSOP-16 | Charger for Ni-MH | 6
51 | U8 | INA219 | Zero-Drift, Bi-Directional CURRENT/POWER MONITOR with I2C. SOIC-8 (D) Package |  | SOIC-8 | Battery current sense | 8
52 | U9 | CH340C | USB to serial chip CH340C, integrated oscillator. |  | SOP-16 | USB to UART & Programming | 3

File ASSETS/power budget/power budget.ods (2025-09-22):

Block | Component | Description/Conditions | Supply voltage (V) | Current consumption per unit (μA) |  | Units | Total dissipated power (μW) |  | Notes
 |  |  |  | Typical | Maximum |  | Typical | Maximum
MCU | ESP32-WROOM-32D | MCU + wireless comm. Module | 3.3 | 70 mA * | 240 mA ** | 1 | 231 mW | 792 mW | * Average, measured, running demo ** Current spikes during wireless TX
Power rails | AP3429 | DC/DC Buck converter IC | 4.2 | 90 μA |  | 1 | 378 μW
 | NCP562SQ18T1G | Low-Dropout regulator IC | 3.3 | 3 μA |  | 1 | 9.9 μW
 | 150 kΩ + 33 kΩ voltage divider | FB pin feedback. Fixed consumption | 3.3 | 18 μA |  | 1 | 59.4 μW
 | [Optional] bypass voltage divider | Assuming 3V3/2 with 10 kΩ resistors | 3.3 | 165 μA |  | 1 | 544.5 μW |  | Consider only if populated
 | Generic 0805 LED | Assuming Vf = 2V & 1 kΩ series resistor | 3.3 | 1.3 mA |  | 1 | 4.3 mW |  | Consider only if populated
Battery & current sense | INA219 | Voltage & current sense IC | 4.2 | 0.7 mA | 1 mA | 1 | 3 mW | 4.2 mW
 | Generic 0805 LED | Assuming Vf = 2V & 1 kΩ series resistor | 5.5 | 1.3 mA |  | 2 | 8.6 mW |  | Consider only if populated |  |  |  | 29.3 ma nimh
 | I2C pull-up resistor | Assuming line level is LOW, with 4.7kΩ resistors | 3.3 | 0.7 mA |  | 2 | 4.6 mW
[Optional] NiMH charger | LTC4060EFE | NiMH/NiCd charger IC | 5.5 | 2.9 mA | 4.3 mA | 1 | 16 mW | 23.7 mW | Consider only the populated charger variant. For charging ICs and BJT: consider only when charging the battery (else they are off). In this case, power consumption comes from external supply not from the internal battery. | NiMH charger worst-case efficiency |  |  |  | Ni-MH charger worst-case efficiency |  |  |  | Lithium charger worst-case efficiency
 | MDJ201 | Power PNP BJT. Ice=0.95 A, Ibe=120mA, Vce=1.8V, Vbe=0.7 V | -- | -- |  | 1 | 1.71 W + 84 mW ≈ 1.8 W |  |  | Power in | Dissipated power | Efficiency |  | Max. Input voltage | Max. Input current | Min. Output voltage | Output current | Max. Input voltage | Max. Input current | Min. Output voltage | Output current
 | 4.42 kΩ + NTC voltage divider | NTC pin. Assuming NTC at 50ºC (3.54 kΩ) | 5.5 | 691 μA |  | 1 | 3.8 mW |  |  | 5.225 W | 1.822 W | 65.10% |  | 5.5 V | 0.95 A + 111.5 mA | 3.3 V | 0.95 A | 5.5 V | 1.0 A + 52.8 mA | 3.6 V | 1.0 A
[Optional] Li-Ion/Li-Po charger | TP4056 | Li-Ion/LiPo charger IC, Vbus-Vbat=1.8 V, Ibat=1 A | 5.5 | 150 μA | 500 μA | 1 | 1.8W + 2.8 mW ≈ 1.8 W |  |  | Lithium charger worst-case efficiency |  |  |  | Maximum power in |  | Minimum power out |  | Maximum power in |  | Output power
 | DW01A | Battery protection IC | 4.2 | 3 μA | 6 μA | 1 | 12.6 μW | 25.6 μW |  | Power in | Dissipated power | Efficiency |  | 5.84 W |  | 3.14 W |  | 5.79 W |  | 3.6 W
 | FS825A | Dual power NMOS, Rds(on)=25 mΩ, Ibat=1 A | -- | -- |  | 1 | 50 mW (both NMOS) |  |  | 5.5 W | 1.878 W | 65.85% |  | Worst-case efficiency | Worst-case efficiency | Worst-case efficiency | Worst-case efficiency | Worst-case efficiency | Worst-case efficiency | Worst-case efficiency | Worst-case efficiency
USB connector | USBLC6-2SC6 | USB ESD protection IC | 5.5 | 10 nA | 150 nA | 1 | 55 nW | 825 nW | Consider only when USB is plugged |  |  |  |  | 53.77% | 53.77% | 53.77% | 53.77% | 62.20% | 62.20% | 62.20% | 62.20%
Programming | CH340C | USB to UART converter IC | 3.3 | 12 mA | 30 mA | 1 | 39.6 mW | 99 mW | Worst case when programming
 | 2N7002 | G.P. NMOS. Ib=0 A, Vds=3.3 V, Ids=330 μA (during conmutation) | -- | -- |  | 2 | 1 mW |  | Consider only when programming
 | Generic 0805 LED | Assuming Vf = 2V & 1 kΩ series resistor | 3.3 | 1.3 mA |  | 4 | 17.2 mW |  | Consider only if populated
Buttons | Pull-up resistors | Assuming line level is LOW, 10kΩ resistors | 3.3 | 330 μA |  | 5 | 5.4 mW |  | Worst case: all pressed at once
Power-up button | BSS84AK | G.P. PMOS. Rsd(on) = 7.5 Ω, Ib=0, Isd = 77 μA | -- | -- |  | 1 | 45 nW
 | 1N4148W | Small signal diode. Vf=0.7 V, If=26 μA | -- | -- |  | 2 | 36.4 μW |  | Worst case: both ON
 | 100 kΩ pull-up resistor | 100 kΩ pull-up resistor | 4.2 | 42 μA |  | 1 | 176.4 μW
TFT LCD display | LCD TFT ILI9341 module | 320x240p LCD (Measured) | 3.3 | 45 mA * | 120 mA ** | 1 | 148.5 mW | 396 mW | * Average, **maximum spike measured, running demo program
Signal conditioning | LMV358DGKR | General purpose dual OpAmp, with no load | 3.3 | 140 μA | 340 μA | 1 | 462 μW | 1.1 mW | Both OpAmps, high Z load
 | 1N4148W | Small signal diode. Vf=0.7 V, If= ? A | -- | -- |  | 4 | -- |  | Unknown
Load cell amplifier | HX711 | Load cell amplifier & ADC IC | 3.3 | 1.4 mA |  | 1 | 4.6 mW |  | Enters sleep if the data clock stops
 | BC858 | General purpose PNP BJT. Vce=1.8V, Ice=? A | -- | -- |  | 1 | -- |  | Unknown
 | 22 kΩ + 10 kΩ voltage divider | VFB pin feedback for AVDD=1.82 V regulation. | 1.82 | 57 μA |  | 1 | 103.7 μW |  | Consider only when HX711 is awake
 |  |  |  | Sum of total current consumption (battery only, not charging) |  |  | Sum of total dissipated power (battery power only, not charging)
 |  |  |  | Typical | Maximum |  | Typical | Maximum
 |  |  |  | 141.8 mA | 405.3 mA | 3.7 V | 469.6 mW | 1342 mW
 |  |  | Capacidad batería |  | 1500 mAh |  |  | 5.55 Wh
 |  |  | Horas de batería |  |  |  | 11.82 horas | 4.14 horas
 |  |  |  | Tener en cuenta las unidades de cada cosa

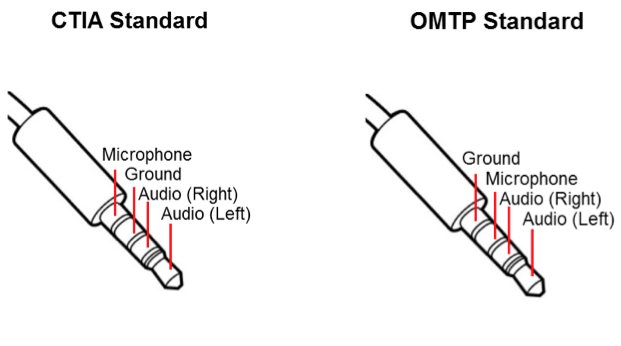
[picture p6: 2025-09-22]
ASSETS/IMAGES/PARTS/JACK/standards.png

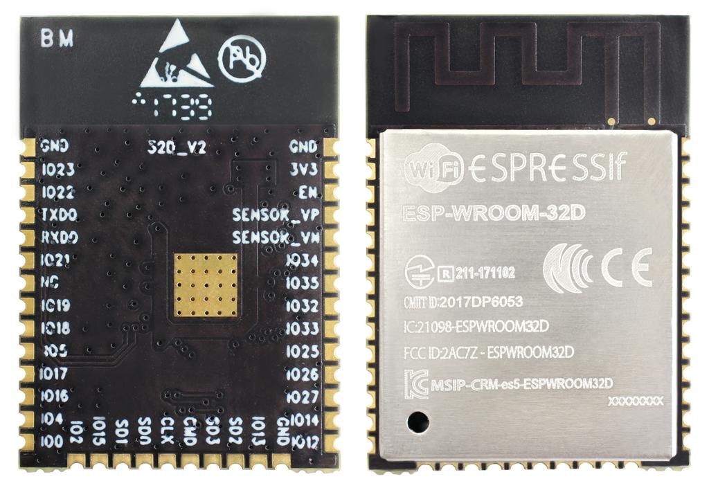
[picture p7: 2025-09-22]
ASSETS/IMAGES/PARTS/ESP32-WROOM-32D/esp-wroom-32d-front-back.jpg

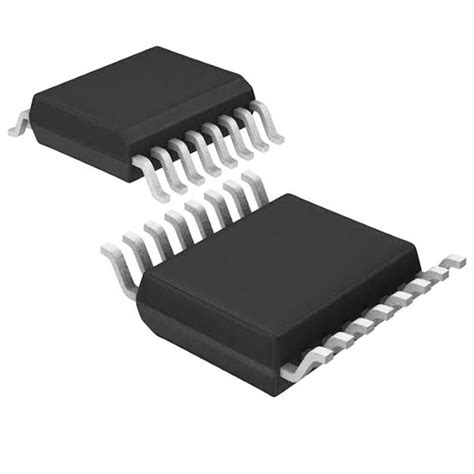
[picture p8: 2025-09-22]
ASSETS/IMAGES/PARTS/LTC4060/TSSOP-16.jpg

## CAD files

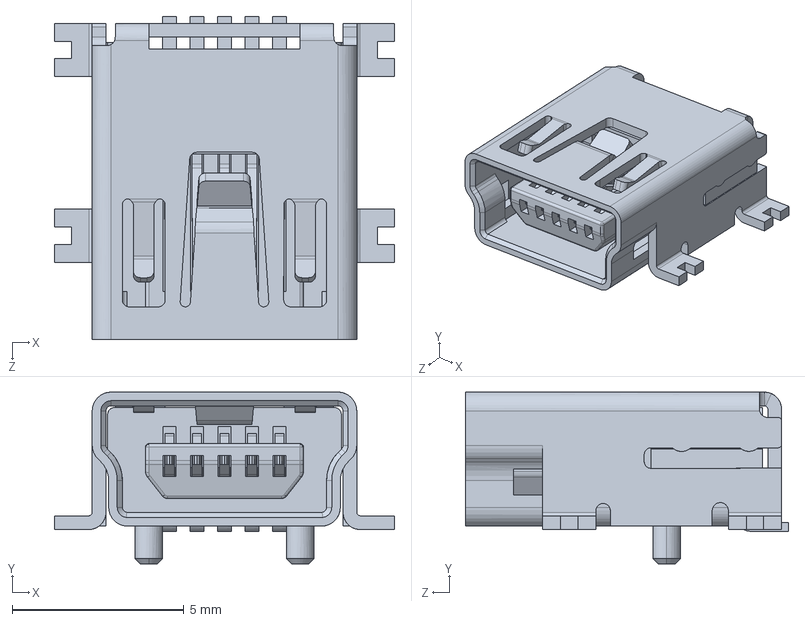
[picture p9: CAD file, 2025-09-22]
ASSETS/3D/USB-MINI-B-10033526-N3212LF/usb_mini_b_10033526-N3212LF.SLDASM
9.90 x 5.00 x 9.40 mm

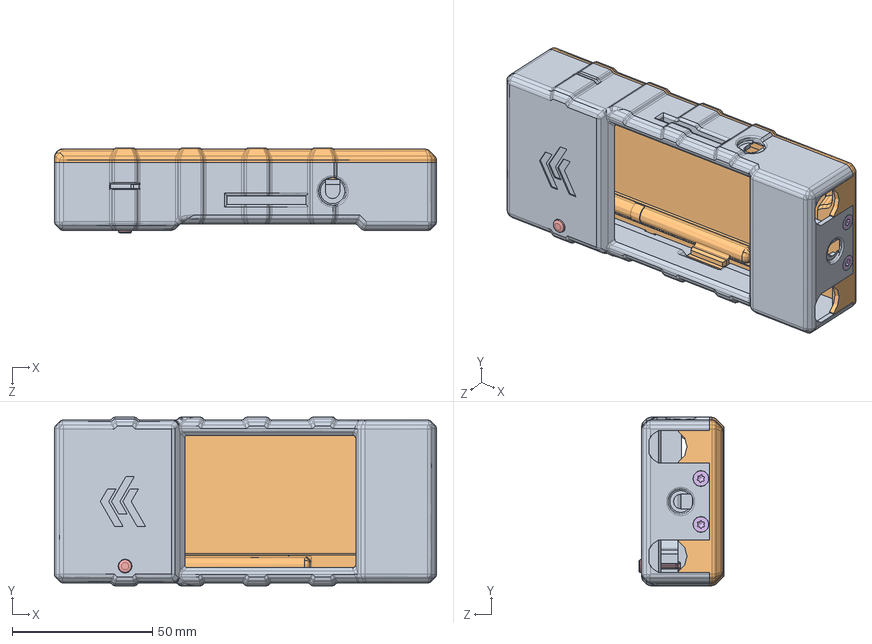
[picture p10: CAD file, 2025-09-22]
ASSETS/TIK_CASE/CASE_ASSEMBLED_NO_PCB.SLDASM
136.0 x 60.0 x 30.4 mm
TOP_COVER
BOTTOM_COVER_FIX
STYLUS
F2-B-M3-Pressfit_2 x 3
BUTTON
hexa csunk flathd screw_iso x 3

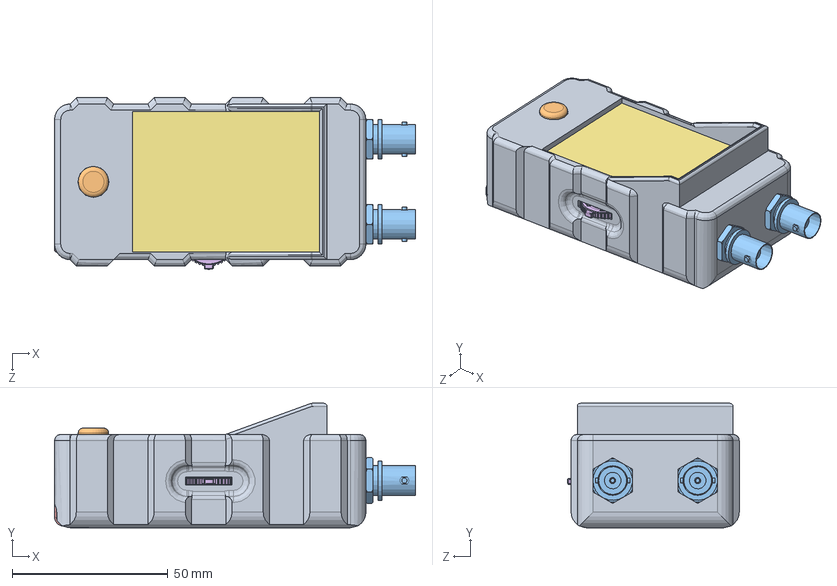
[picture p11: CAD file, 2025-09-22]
ASSETS/TIK_CASE/PROTO/PROTO_ASM.SLDASM
115.9 x 40.0 x 55.1 mm
CASE_PROTO
boton
ACX1046-ND_BNC x 2
1.2.igs.STEP
STYLUS
SLLB510100_SCALED_CROP.step
SCREEN

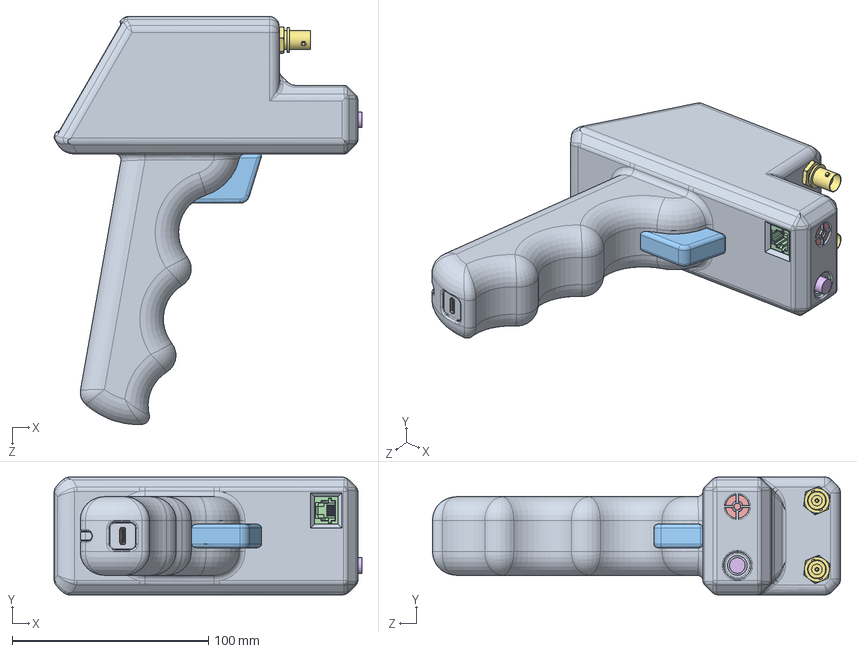
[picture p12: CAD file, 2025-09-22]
ASSETS/TIK_CASE/FUTURE/future.SLDASM
156.5 x 60.0 x 207.6 mm
PISTOL
CUI_DEVICES_UJC-VP-3-SMT-TR
BUTTON
438600026.stp
micro
embolo
ACX1046-ND_BNC x 2
SCREEN
STYLUS

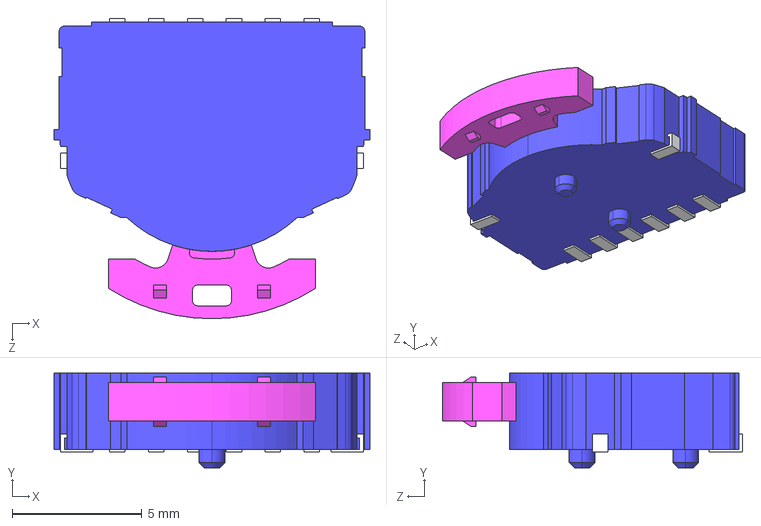
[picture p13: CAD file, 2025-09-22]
ASSETS/3D/Alps Alpine SLLB/sllb120100/SLLB120100.STEP
12.2 x 3.65 x 11.6 mm

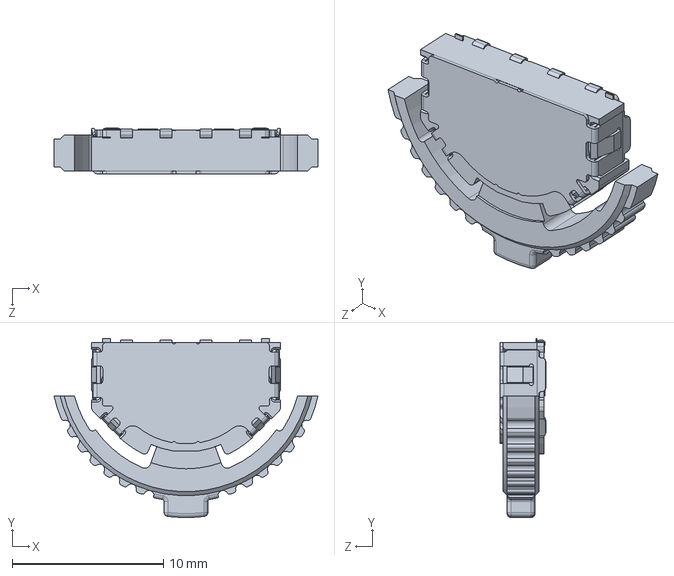
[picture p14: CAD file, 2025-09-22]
ASSETS/3D/Alps Alpine SLLB/SLLB510100.step.SLDPRT
17.5 x 11.8 x 3.02 mm

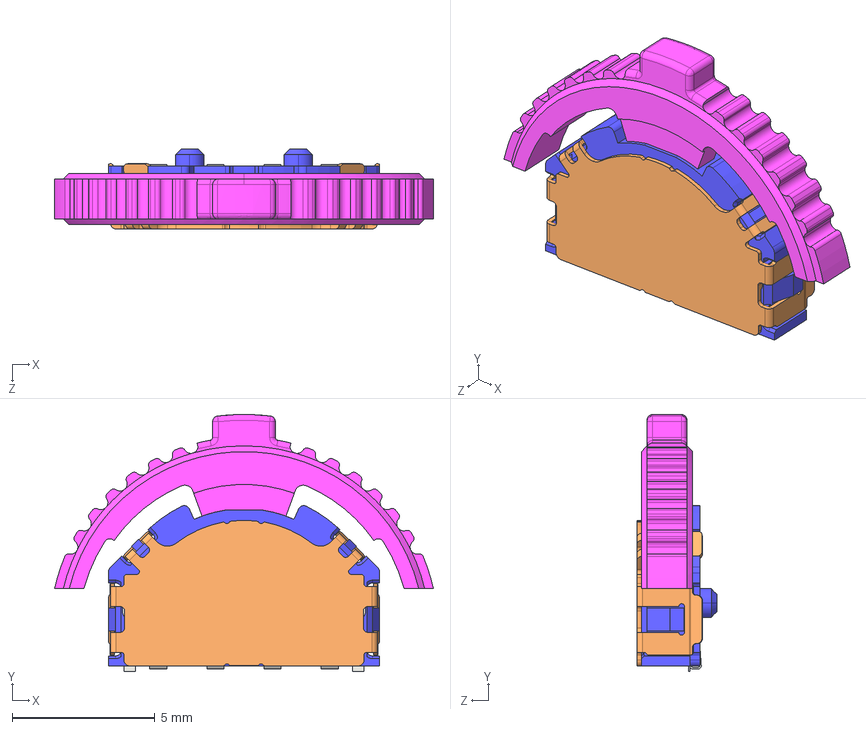
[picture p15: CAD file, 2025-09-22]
ASSETS/3D/Alps Alpine SLLB/sllb510100/SLLB510100.STEP
13.3 x 9.00 x 2.80 mm

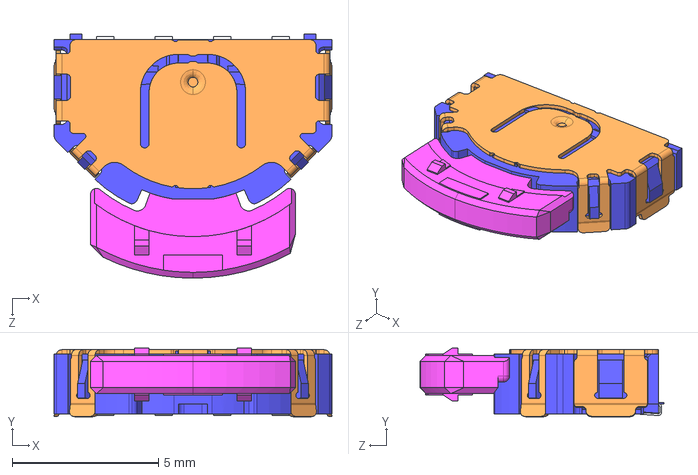
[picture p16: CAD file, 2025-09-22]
ASSETS/3D/Alps Alpine SLLB/sllb520200/SLLB520200.STEP
9.50 x 2.34 x 8.35 mm

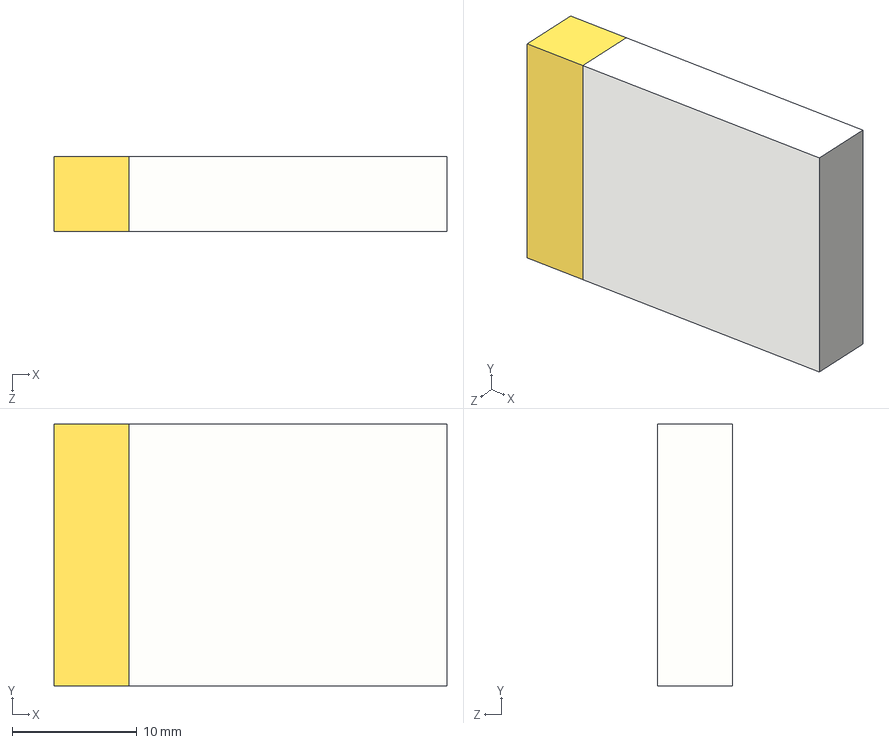
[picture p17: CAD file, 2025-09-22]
ASSETS/3D/BATTERY/300mAh_Lipo_Battery_TRAN.STEP
31.5 x 21.0 x 6.00 mm
IC_board.step
101_smd_resistor.step
102_smd_resistor.step
DW01-P.step
8205A.step
smd_capacitor.step
Lipo_Body.step

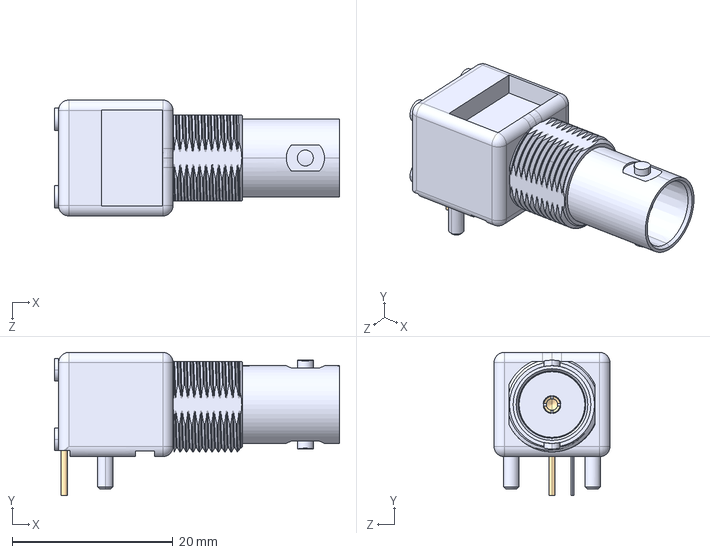
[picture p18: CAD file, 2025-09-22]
ASSETS/3D/BNC/31-71043_1.stp
35.4 x 17.8 x 14.4 mm

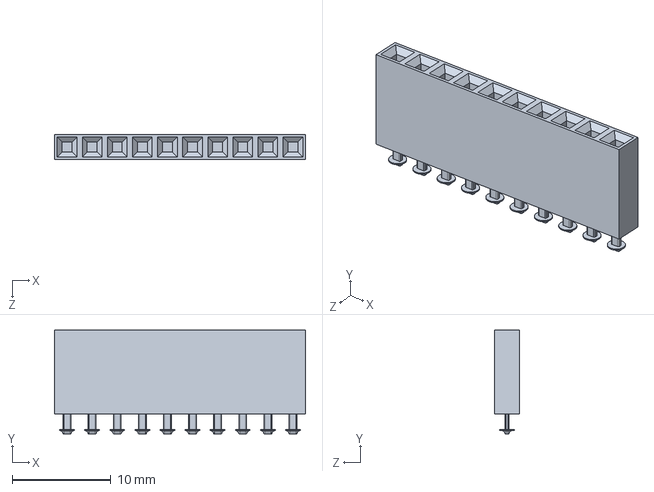
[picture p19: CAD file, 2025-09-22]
ASSETS/3D/FEMALE HEADER PIN ARRAY/ROW HEADER Parametric.SLDPRT
25.4 x 10.5 x 2.54 mm

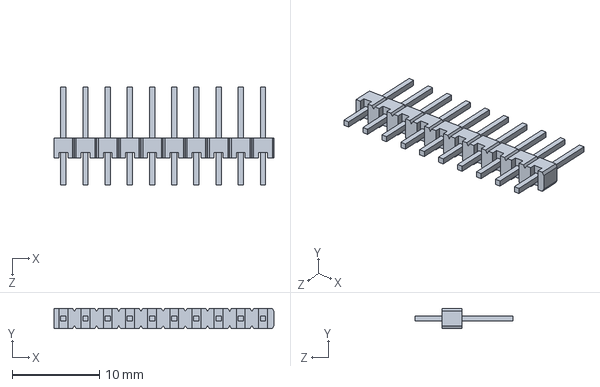
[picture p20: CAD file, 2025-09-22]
ASSETS/3D/MALE HEADER PIN ARRAY/10PIN.SLDPRT
25.2 x 2.34 x 11.2 mm

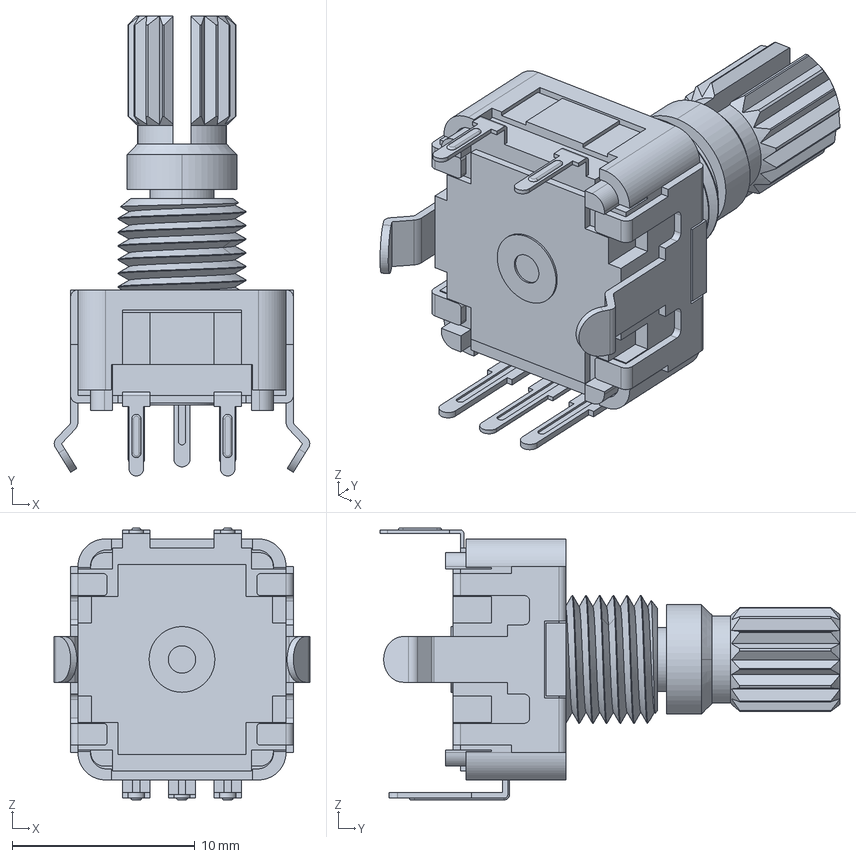
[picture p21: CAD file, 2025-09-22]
ASSETS/3D/Rotary Encoder PEC11/pec11r-4x15k-sxxxx.stp
14.0 x 25.2 x 14.9 mm

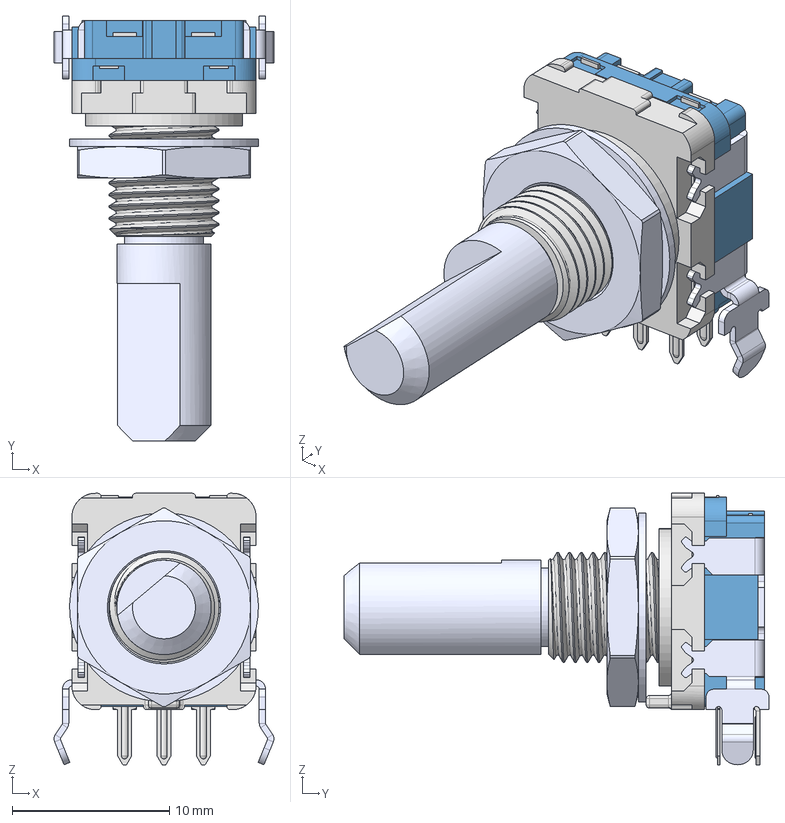
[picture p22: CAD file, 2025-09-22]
ASSETS/3D/Rotary encoder right angle generic/EC11B-SW-Horiz-20F-blue.step
14.0 x 27.0 x 17.3 mm

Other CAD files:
ASSETS/3D/Rotary encoder vertical generic/EC11B-SW-Vert-20F-blue.step
ASSETS/3D/SC-82AB/sc_82ab.step
ASSETS/3D/SPACER/Standoff mf - M5 x 30 across flats 8mm.step
ASSETS/3D/THREADED INSERT/F2-B-M3-Pressfit_2.STEP
ASSETS/3D/Alps Alpine SLLB/SLLB120100.SLDPRT
ASSETS/3D/Alps Alpine SLLB/SLLB510100.STEP
ASSETS/3D/Alps Alpine SLLB/SLLB510100_SCALED.STEP
ASSETS/3D/Alps Alpine SLLB/SLLB520200.SLDPRT
ASSETS/3D/Alps Alpine SLLB/SLLB520200.STEP
ASSETS/3D/BATTERY/1100mAh lipo v8.step
ASSETS/3D/BATTERY/300mAh_Lipo_Battery.SLDASM
ASSETS/3D/BATTERY/300mAh_Lipo_Battery.step
ASSETS/3D/BATTERY/LIPO_604060.STEP
ASSETS/3D/BATTERY/LIPO_803035.SLDPRT
ASSETS/3D/BATTERY/LIPO_803035.STEP
ASSETS/3D/BATTERY/LIPO_805660.SLDPRT
ASSETS/3D/BATTERY/LIPO_805660.STEP
ASSETS/3D/BATTERY/Li Bat 503035P.step
ASSETS/3D/BNC/31-71043.SLDPRT
ASSETS/3D/BNC/31-71043.stp
ASSETS/3D/FEMALE HEADER PIN ARRAY/FEMALE_THT_11X2.stp
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

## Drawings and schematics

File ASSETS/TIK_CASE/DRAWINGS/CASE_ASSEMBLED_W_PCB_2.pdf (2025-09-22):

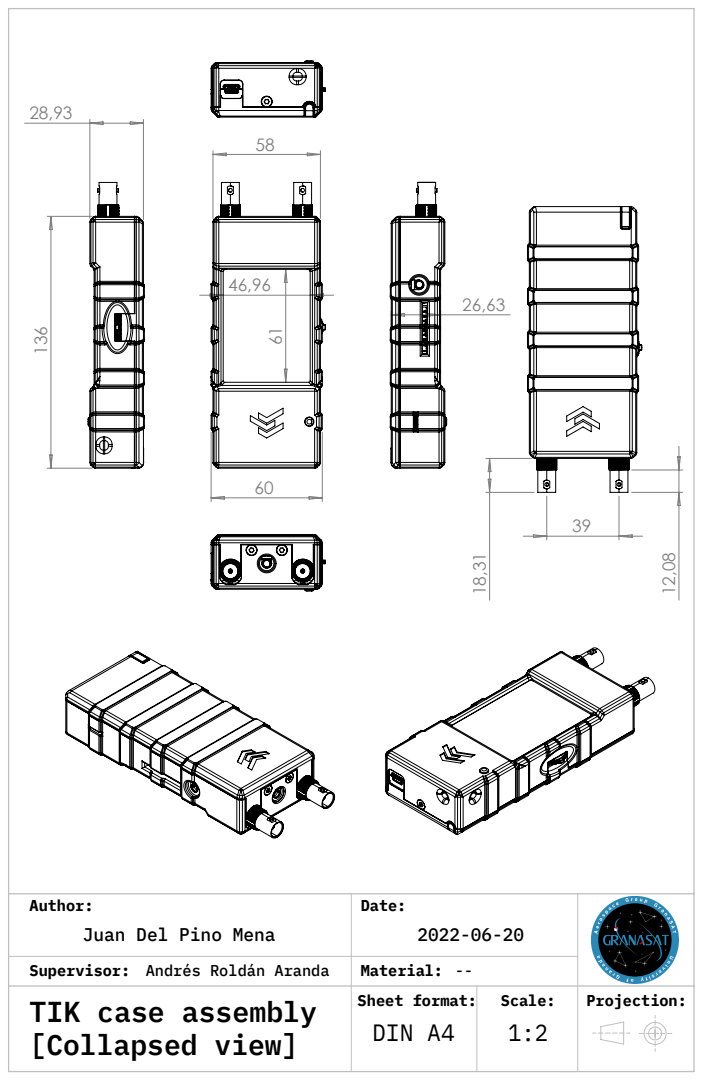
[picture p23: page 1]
Sheet format: Scale:; Projection:; Juan Del Pino Mena; DIN A4; 1:2 TIK case assembly; [Collapsed view]; Andrés Roldán Aranda

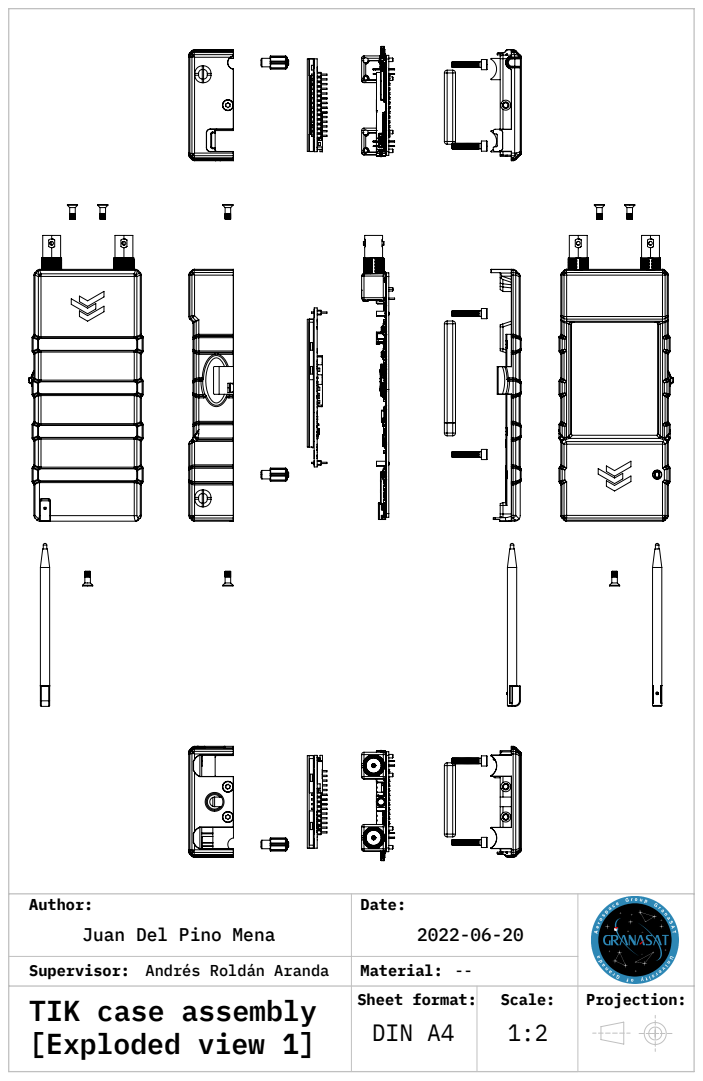
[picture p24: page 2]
Andrés Roldán Aranda; [Exploded view 1]; TIK case assembly; DIN A4; Juan Del Pino Mena; Sheet format: Scale:; Projection:

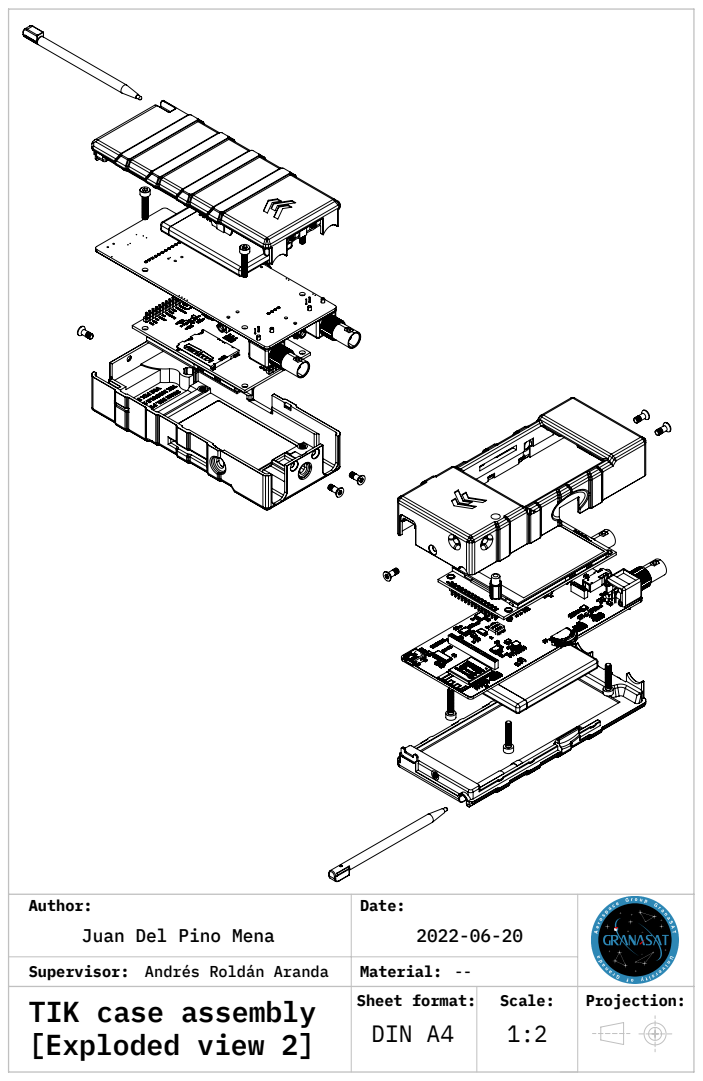
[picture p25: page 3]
Sheet format: Scale:; Projection:; Juan Del Pino Mena; DIN A4; 1:2 TIK case assembly; [Exploded view 2]; Andrés Roldán Aranda

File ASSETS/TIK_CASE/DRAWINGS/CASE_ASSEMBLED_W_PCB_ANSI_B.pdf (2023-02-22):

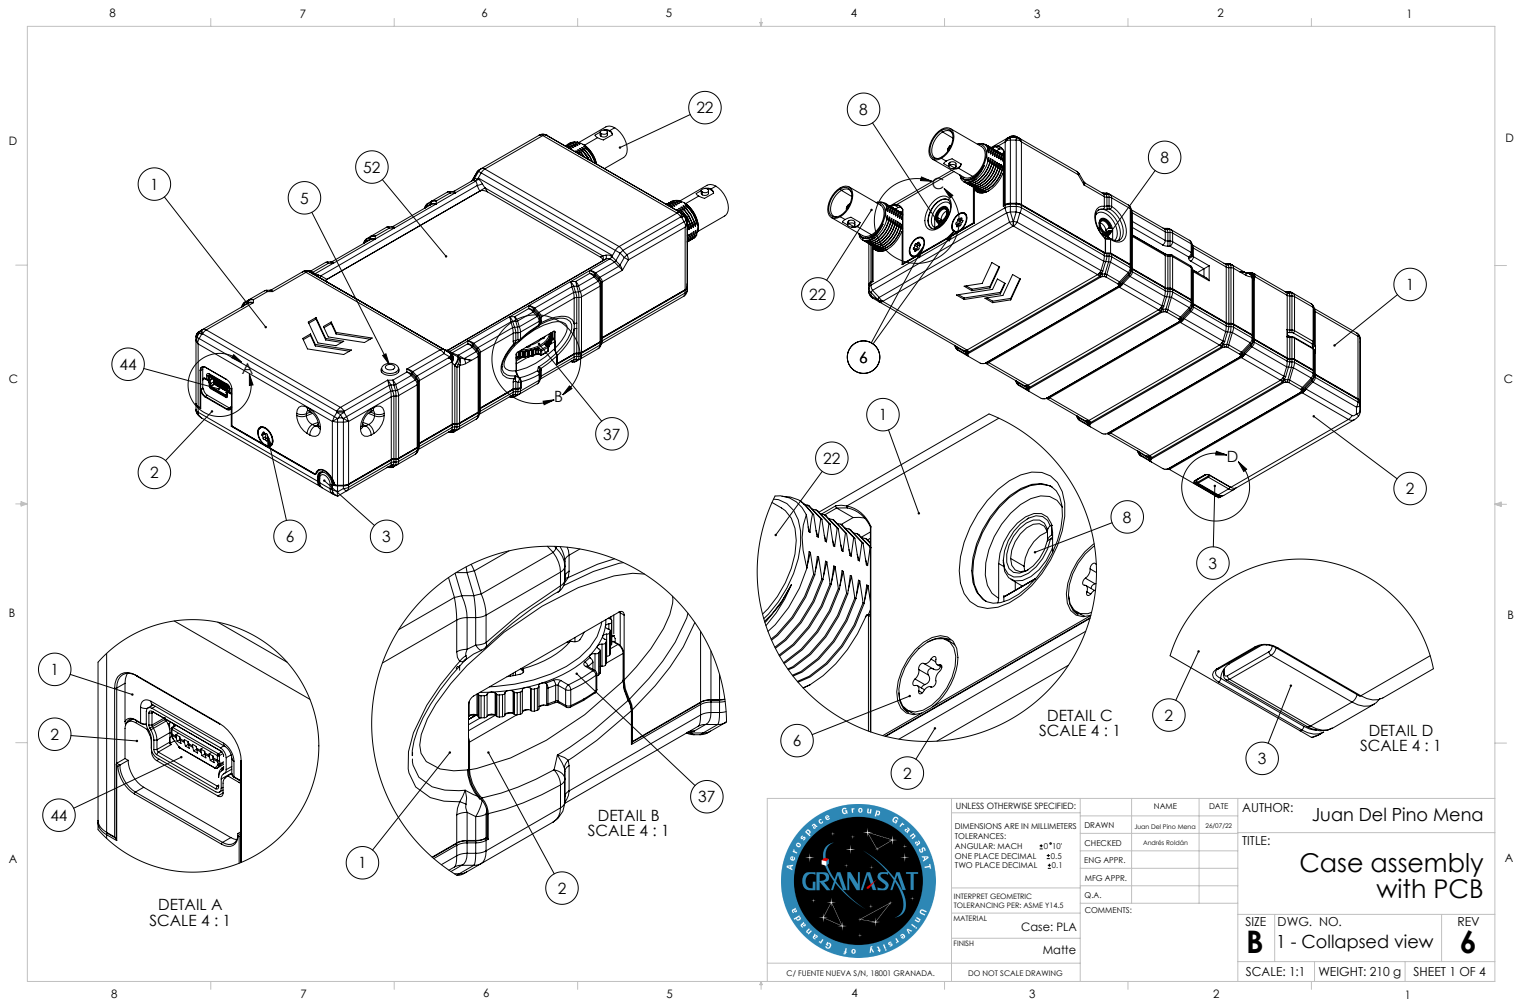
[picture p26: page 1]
DETAIL A SCALE 4 : 1; DETAIL B; SCALE 4 : 1; DETAIL D SCALE 4 : 1; DETAIL C SCALE 4 : 1 6; 1 - Collapsed view; ANGULAR: MACH; ONE PLACE DECIMAL; TWO PLACE DECIMAL; Case: PLA; ENG APPR.; MFG APPR.; NAME; DATE; Juan Del Pino Mena; DWG. NO.; REV; SCALE: 1:1 WEIGHT: 210 g; SHEET 1 OF 4; Case assembly with PCB

UNLESS OTHERWISE SPECIFIED:

DIMENSIONS ARE IN MILLIMETERS
TOLERANCES:

Juan Del Pino Mena 26/07/22
Andrés Roldán

INTERPRET GEOMETRIC
TOLERANCING PER: ASME Y14.5
MATERIAL

C/ FUENTE NUEVA S/N, 18001 GRANADA.

DO NOT SCALE DRAWING

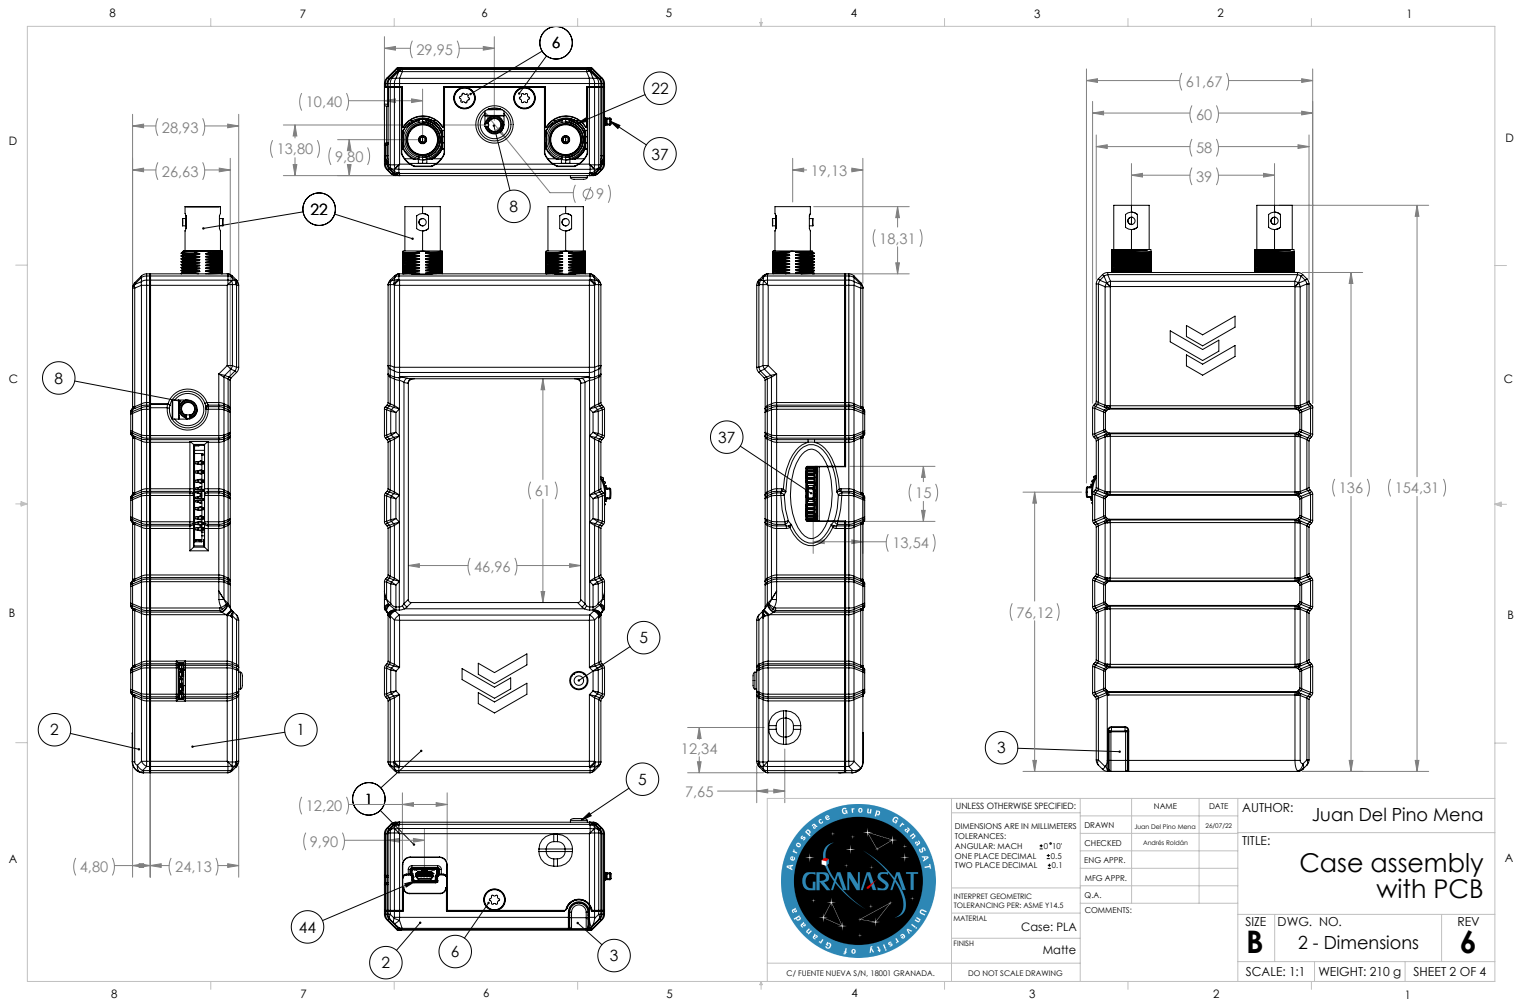
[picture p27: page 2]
ANGULAR: MACH; ONE PLACE DECIMAL; TWO PLACE DECIMAL; Case: PLA; ENG APPR.; MFG APPR.; NAME; DATE; Juan Del Pino Mena; DWG. NO.; REV; Case assembly with PCB; 2 - Dimensions

UNLESS OTHERWISE SPECIFIED:

DIMENSIONS ARE IN MILLIMETERS
TOLERANCES:

Juan Del Pino Mena 26/07/22
Andrés Roldán

INTERPRET GEOMETRIC
TOLERANCING PER: ASME Y14.5
MATERIAL

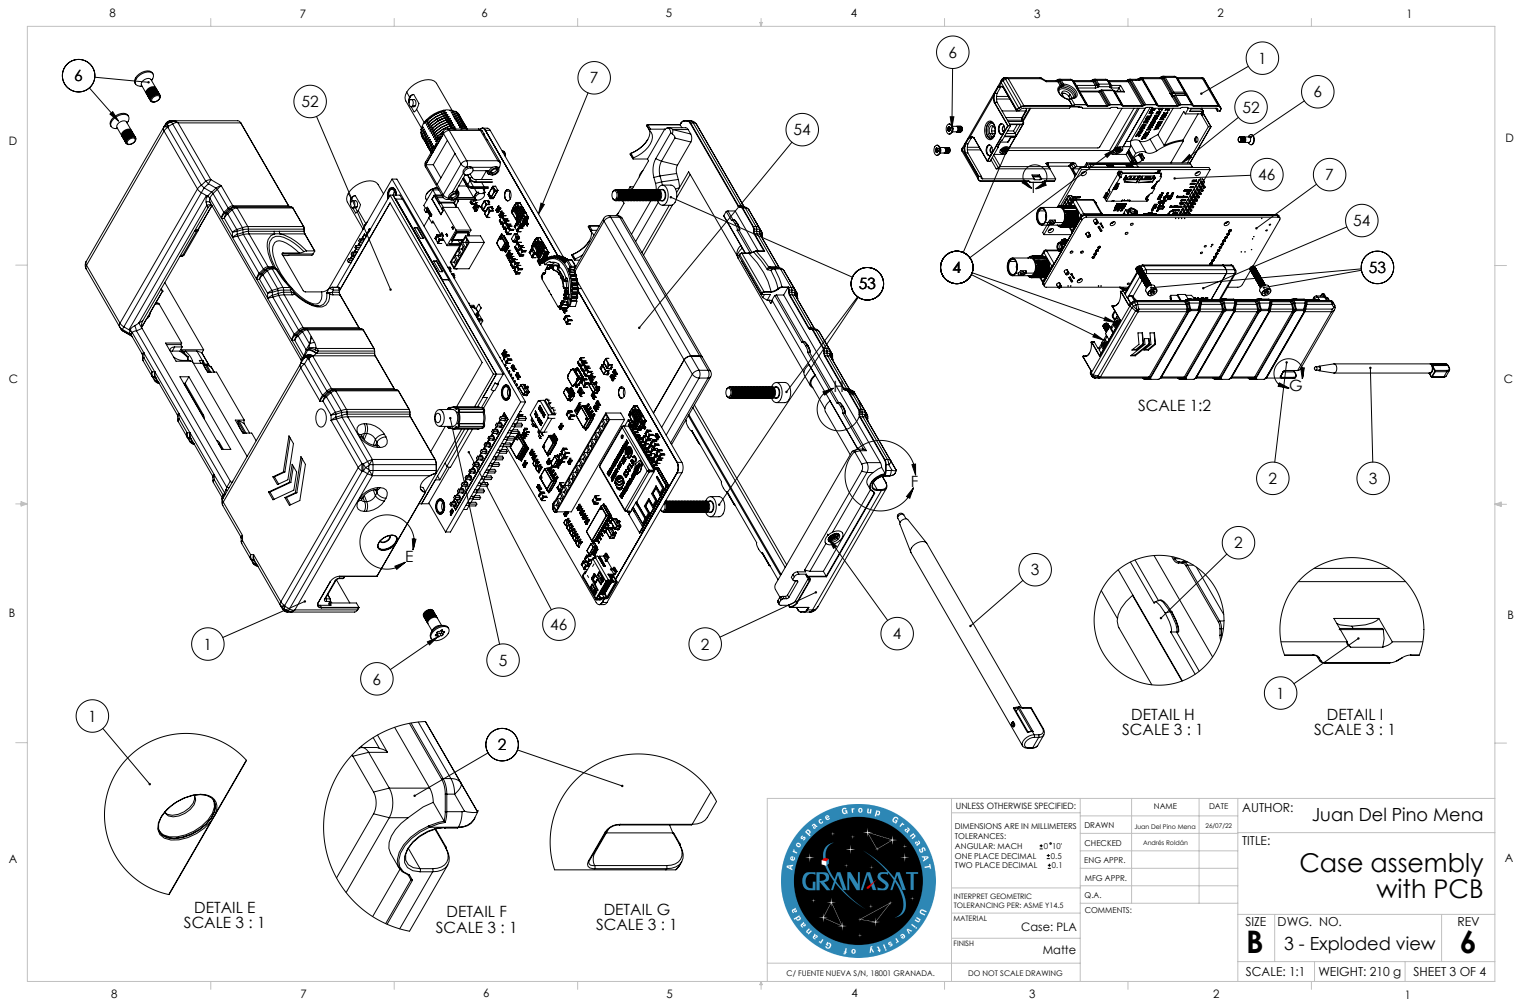
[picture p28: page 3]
SCALE 1:2; DETAIL E SCALE 3 : 1; DETAIL I; SCALE 3 : 1; DETAIL H SCALE 3 : 1; DETAIL F SCALE 3 : 1; DETAIL G SCALE 3 : 1; ANGULAR: MACH; ONE PLACE DECIMAL; TWO PLACE DECIMAL; Case: PLA; ENG APPR.; MFG APPR.; NAME; DATE; Juan Del Pino Mena; DWG. NO.; REV; Case assembly with PCB; 3 - Exploded view 6

UNLESS OTHERWISE SPECIFIED:

DIMENSIONS ARE IN MILLIMETERS
TOLERANCES:

Juan Del Pino Mena 26/07/22
Andrés Roldán

INTERPRET GEOMETRIC
TOLERANCING PER: ASME Y14.5
MATERIAL

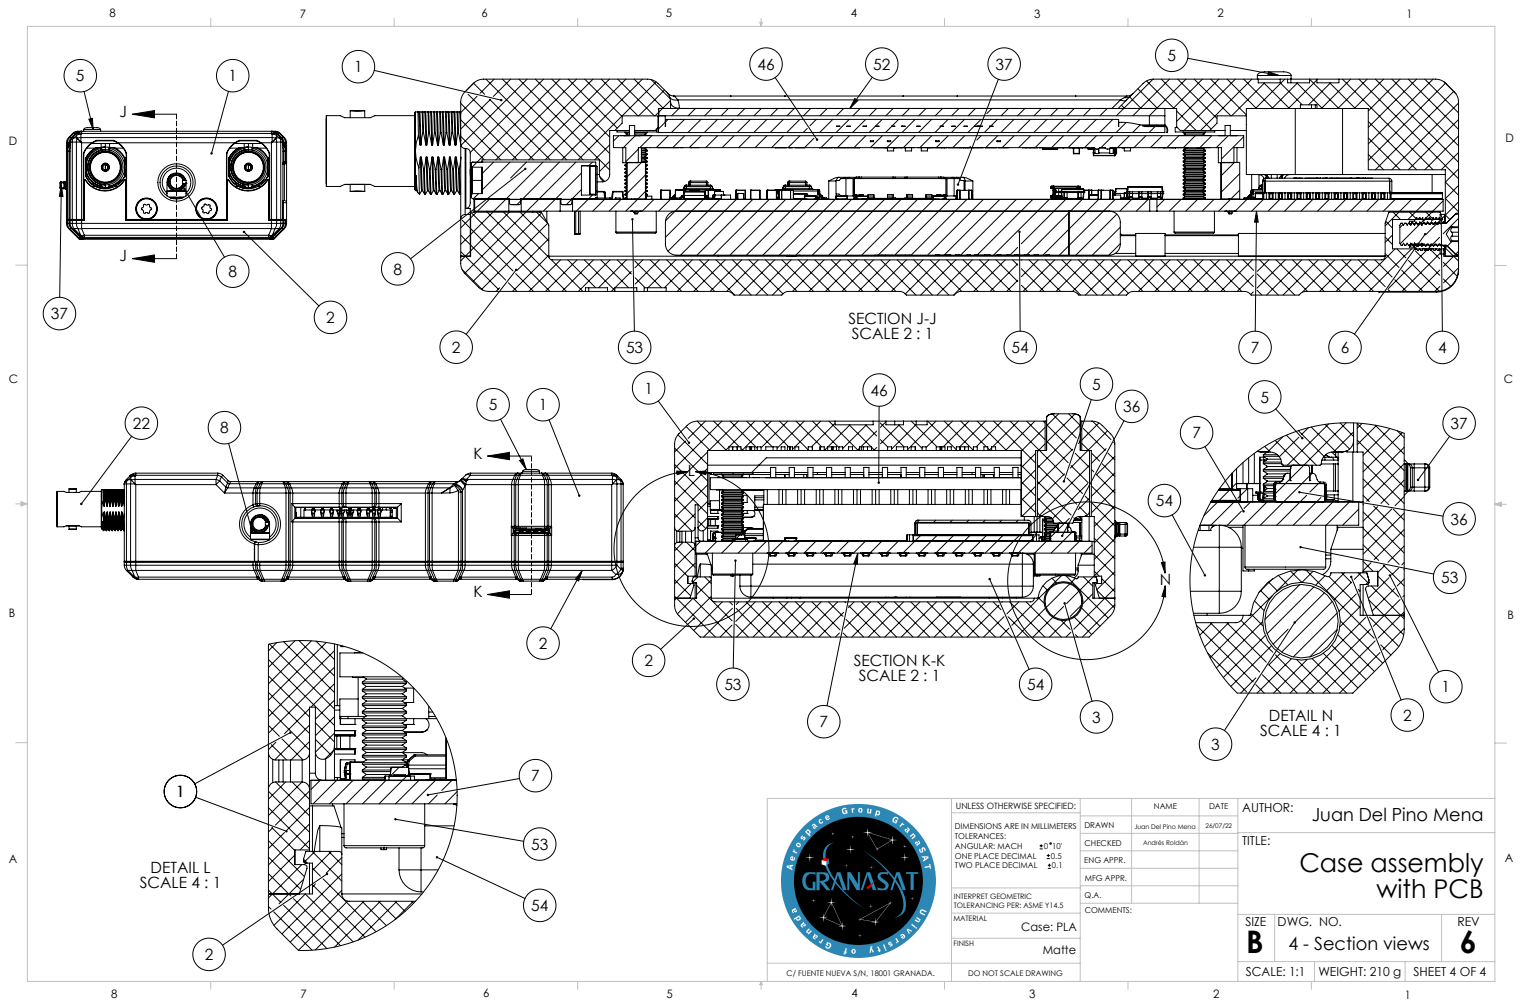
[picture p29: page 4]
SECTION J-J; SCALE 2 : 1; SECTION K-K SCALE 2 : 1; DETAIL N; SCALE 4 : 1; DETAIL L SCALE 4 : 1; ANGULAR: MACH; ONE PLACE DECIMAL; TWO PLACE DECIMAL; Case: PLA; ENG APPR.; MFG APPR.; NAME; DATE; Juan Del Pino Mena; DWG. NO.; REV; Case assembly with PCB; 4 - Section views

UNLESS OTHERWISE SPECIFIED:

DIMENSIONS ARE IN MILLIMETERS
TOLERANCES:

Juan Del Pino Mena 26/07/22
Andrés Roldán

INTERPRET GEOMETRIC
TOLERANCING PER: ASME Y14.5
MATERIAL

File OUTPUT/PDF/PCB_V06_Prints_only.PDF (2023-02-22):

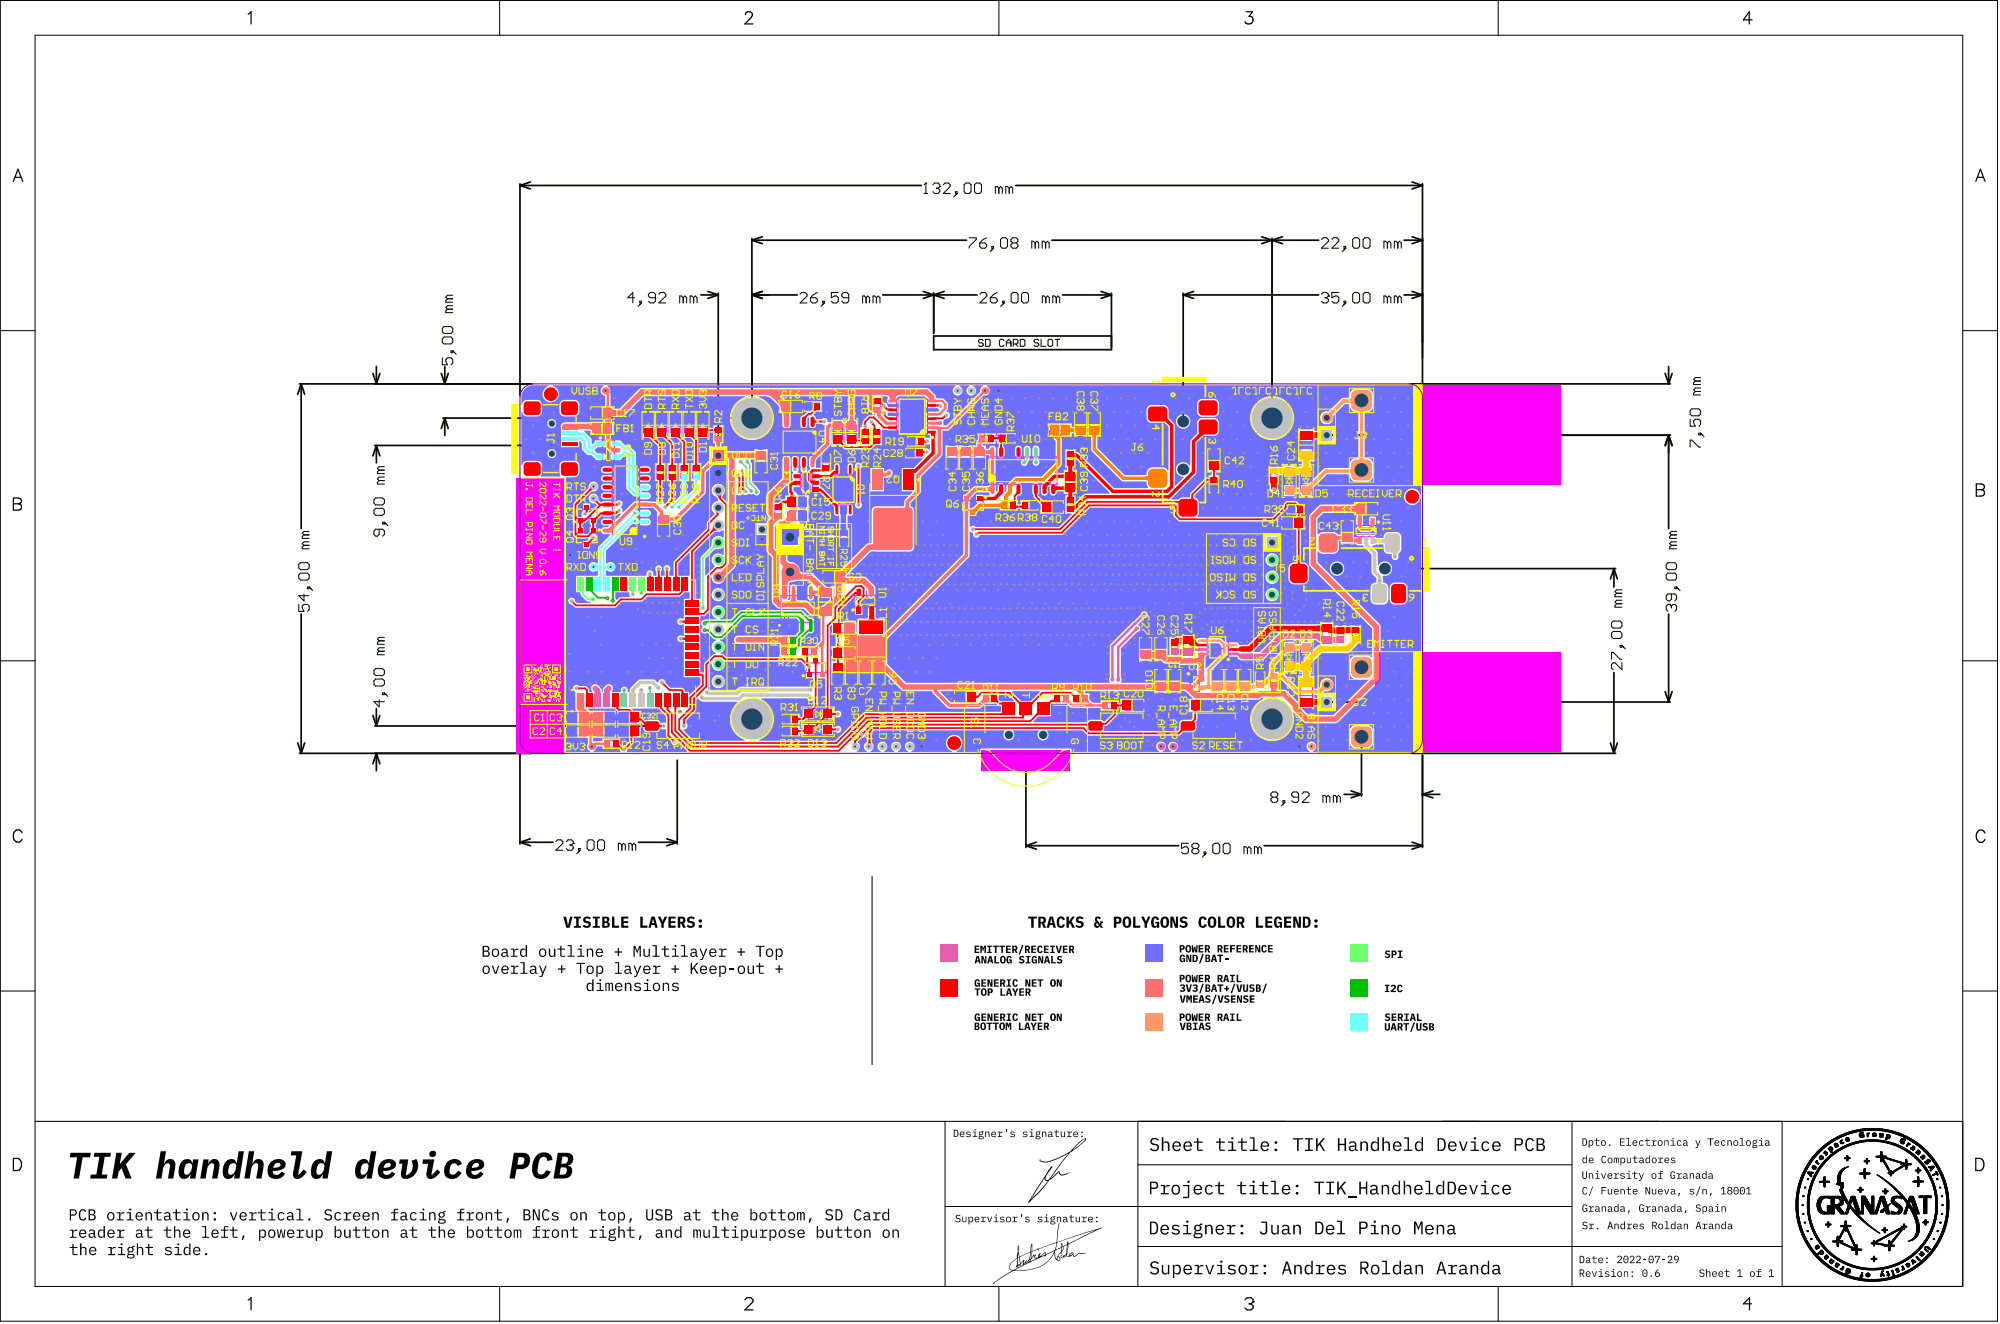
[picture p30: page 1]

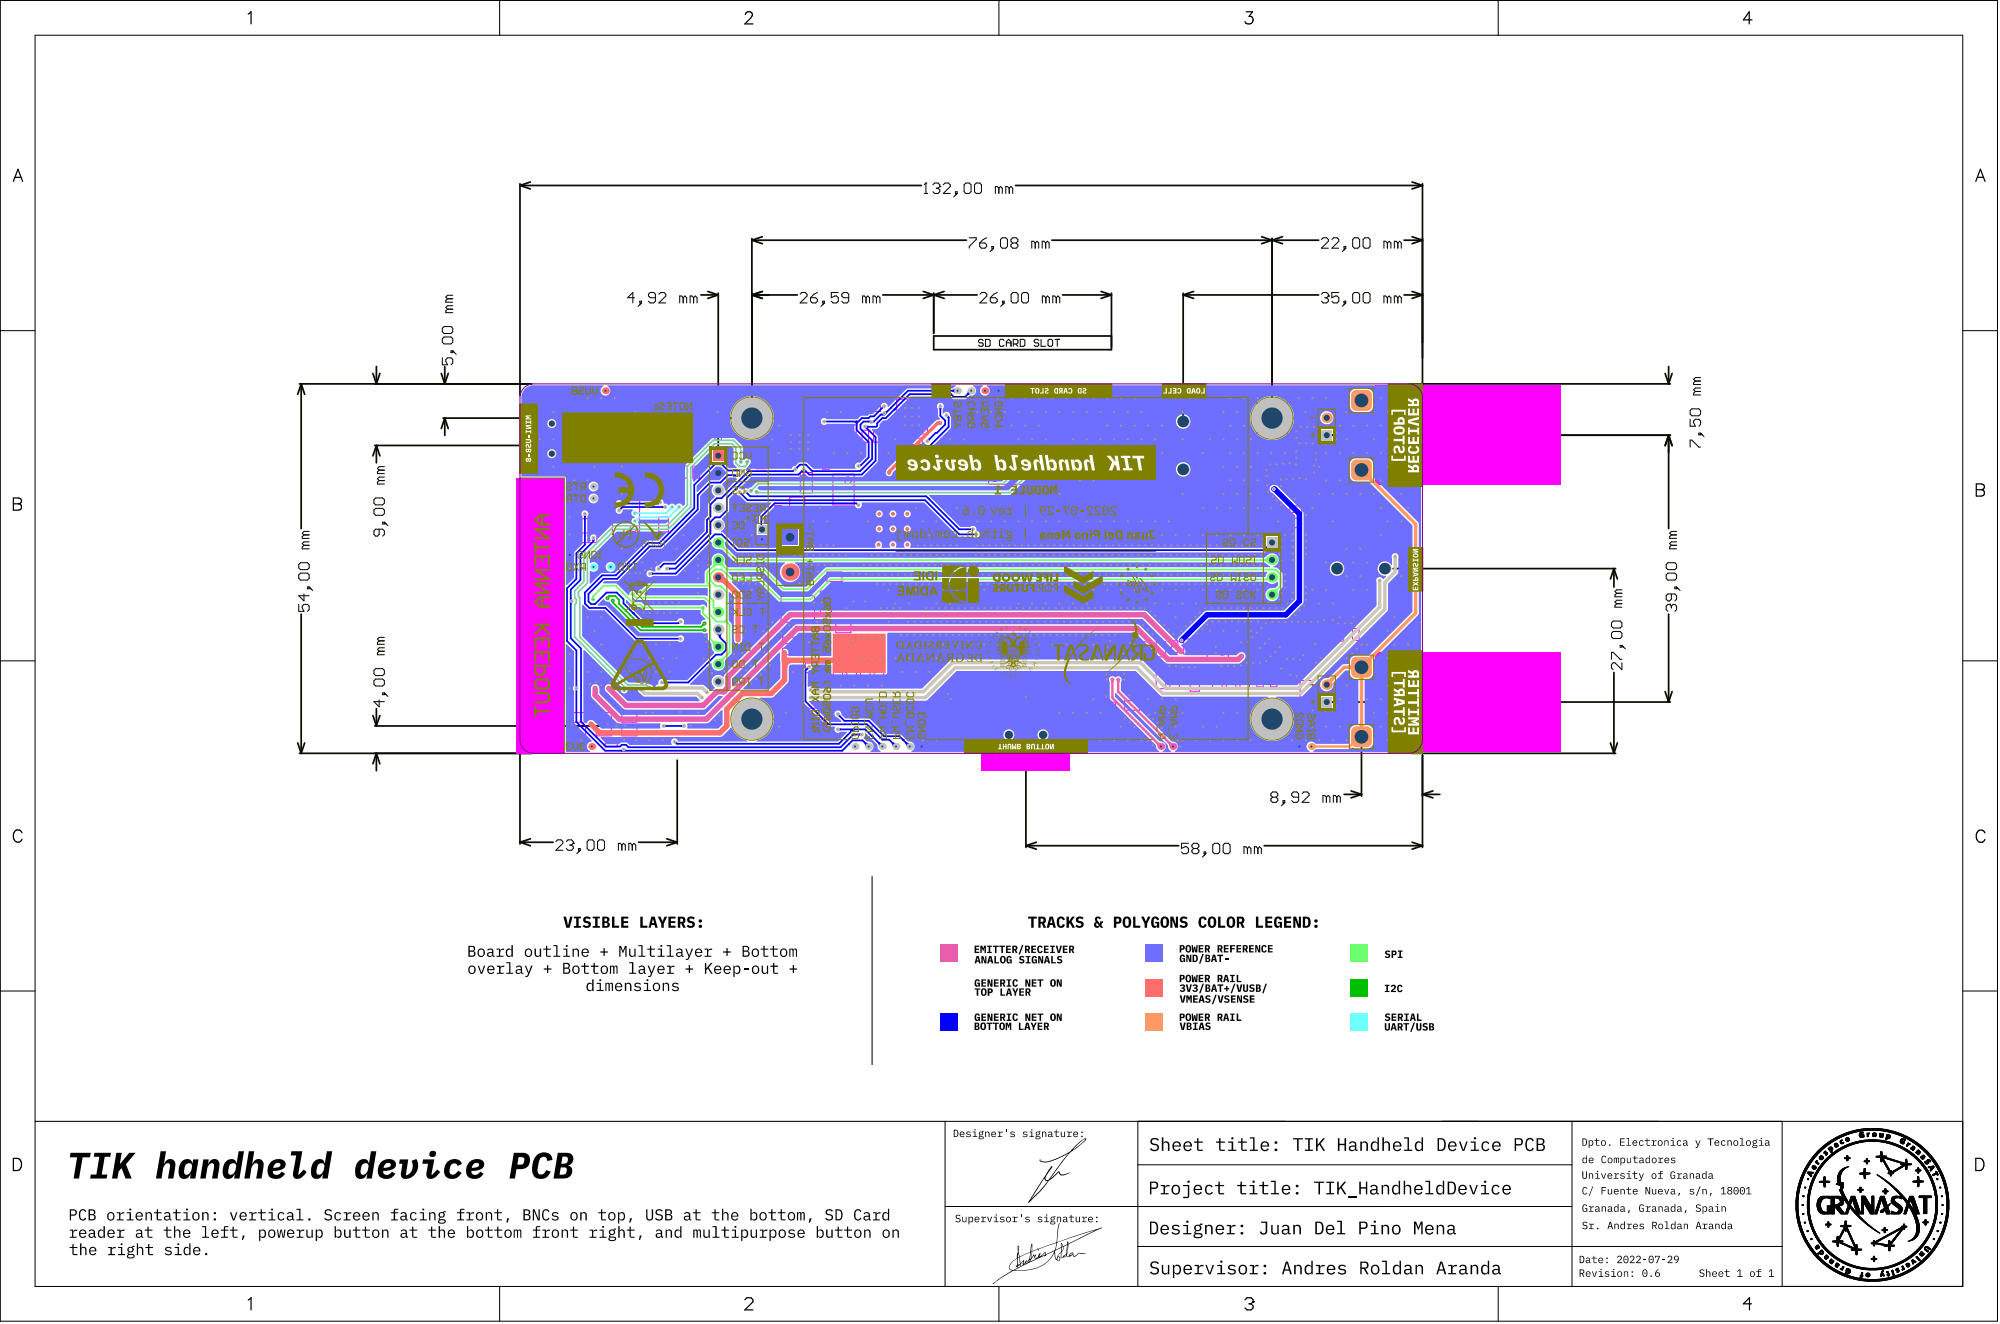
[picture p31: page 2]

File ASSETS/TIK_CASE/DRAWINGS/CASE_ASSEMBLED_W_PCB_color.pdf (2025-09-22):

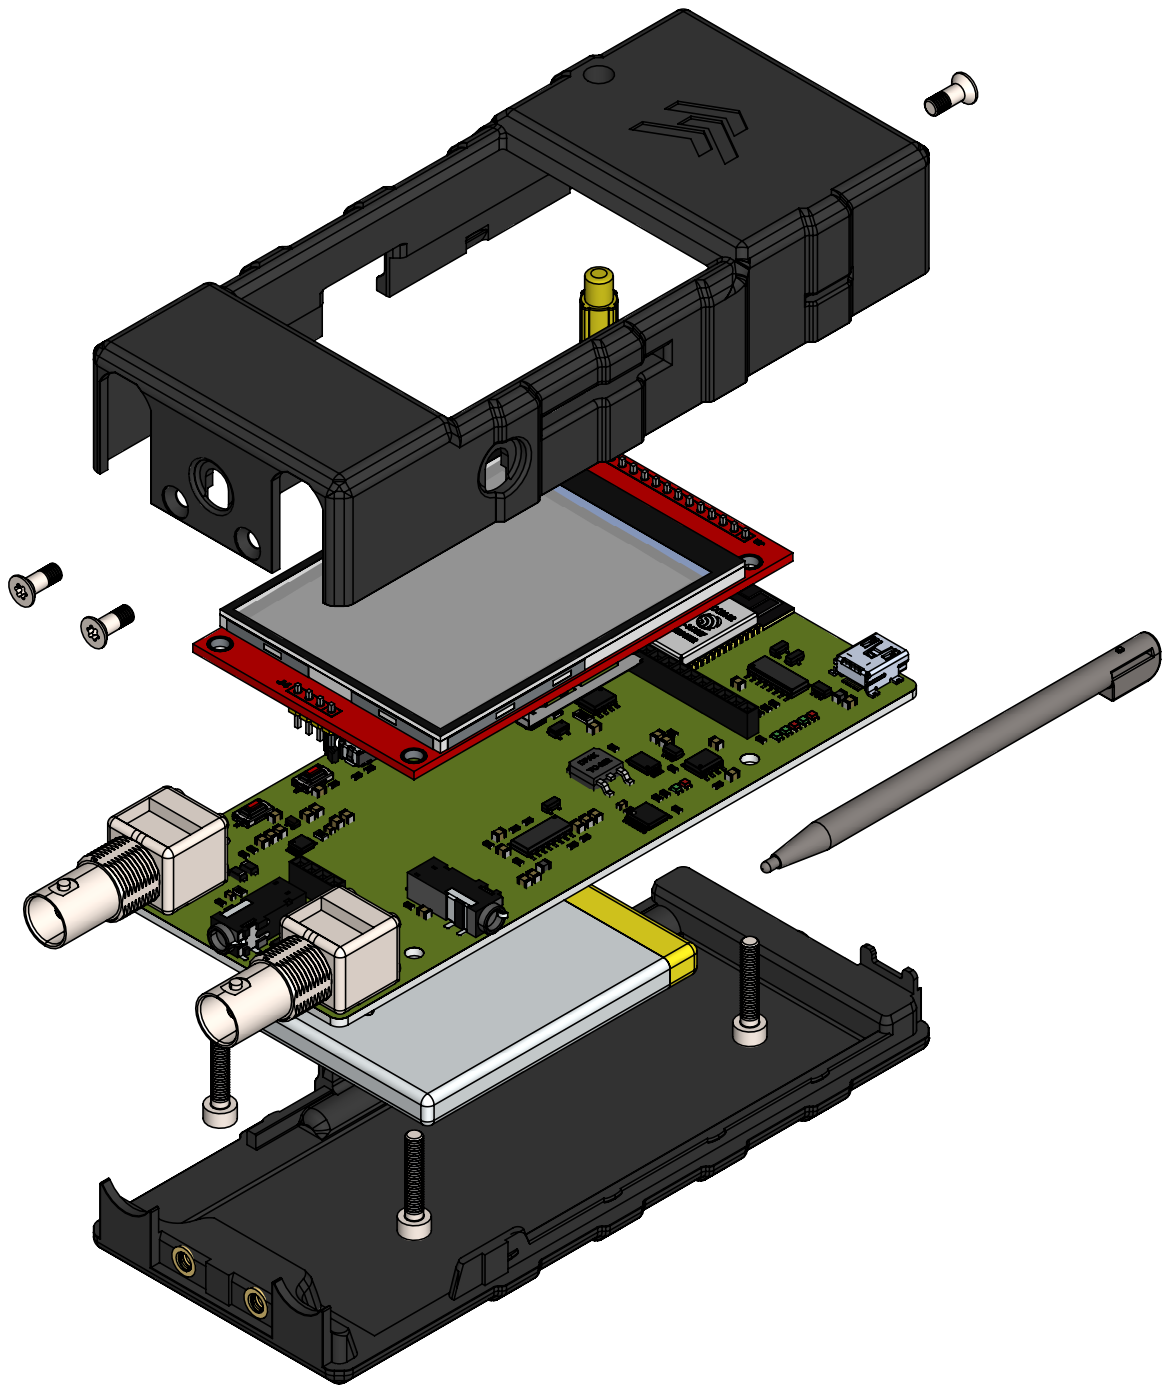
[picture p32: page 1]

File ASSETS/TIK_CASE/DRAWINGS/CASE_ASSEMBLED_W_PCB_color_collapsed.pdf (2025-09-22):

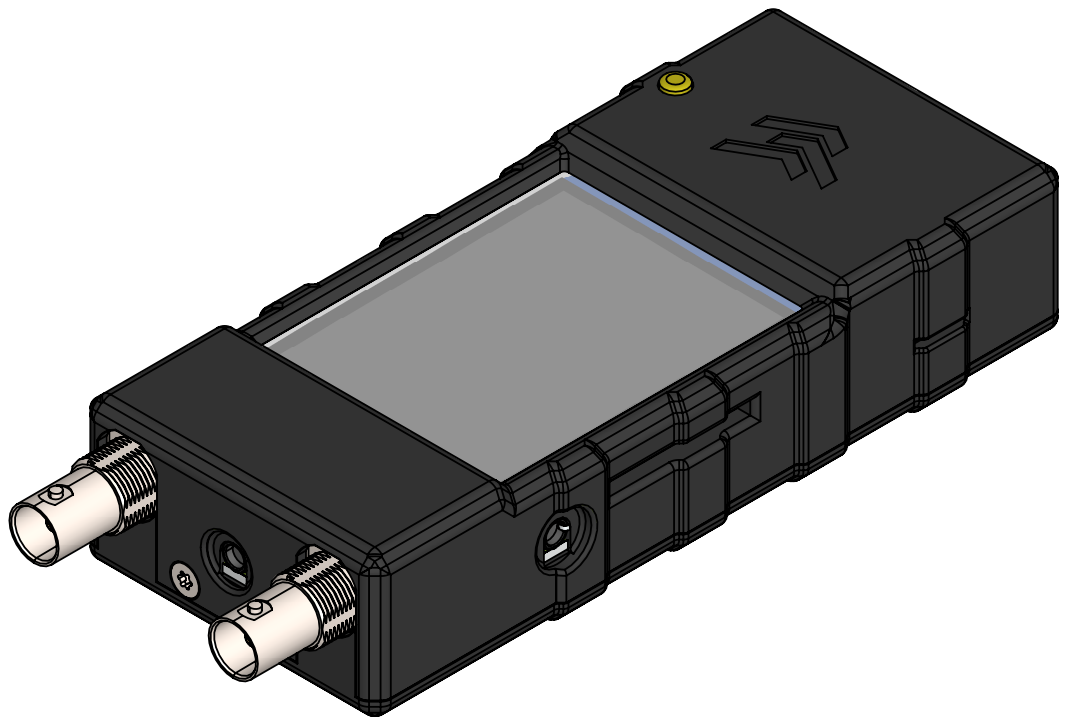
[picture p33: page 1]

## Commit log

2025-09-22 added hardware source
    [10PIN.SLDPRT, 1100mAh lipo v8.step, 300mAh_Lipo_Battery.SLDASM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]
2025-09-22 added mechanical design
    [438600026.stp.SLDPRT, ACX1046-ND_BNC.SLDPRT, ACX1046-ND_BNC.STEP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]
